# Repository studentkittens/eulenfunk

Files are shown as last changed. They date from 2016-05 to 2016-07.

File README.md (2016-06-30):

# Eulenfunk

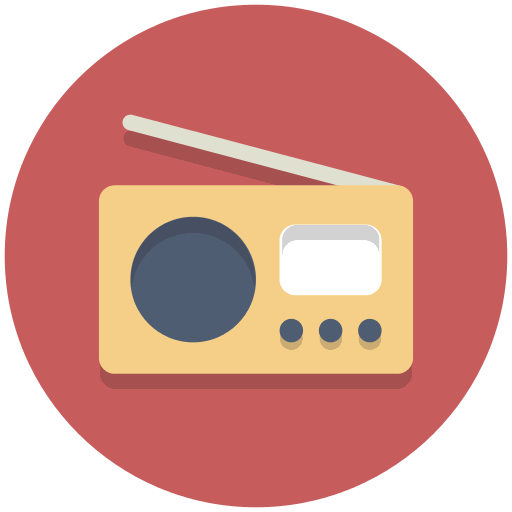
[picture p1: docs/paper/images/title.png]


A Webradio for the kitchen based on the Raspberry PI. [Go watch it in action!](https://vimeo.com/171646691)

The documentation can be found [here](https://studentkittens.github.io/eulenfunk/eulenfunk-doc.pdf).
Some slides [are available too](https://studentkittens.github.io/eulenfunk/index.html).

Sadly, both are in german. We're happy to answer questions though.

<iframe src="https://player.vimeo.com/video/171646691" width="640" height="360"
frameborder="0" webkitallowfullscreen mozallowfullscreen
allowfullscreen></iframe>

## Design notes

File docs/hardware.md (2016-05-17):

# Hardware-Komponenten

 - vorhanden:
    * RaspberryPi
    * LCD
    * Lautsprecher
    * Soundkarte
    * Ein-/Ausschalter
  
 - zu beschaffen:
    * Netzteil
    * Verstärker für Lautsprecher
    * Drehimpulsregler: ALPS-STEC11B03, evtl. 2x
    * muli-color-LED: Wieviele sind möglich?

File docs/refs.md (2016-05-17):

# Pin-Belegung/Rev:

http://www.raspberrypi-spy.co.uk/2012/09/checking-your-raspberry-pi-board-version/
http://www.hobbytronics.co.uk/raspberry-pi-gpio-pinout

# Archlinux ARM

https://archlinuxarm.org/platforms/armv6/raspberry-pi

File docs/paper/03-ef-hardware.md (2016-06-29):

# Hardware

## Anforderungen

Das Radio soll dem Benutzer folgende Hardwarekonfigurationsmöglichkeiten bieten:

* Anschluss passive Lautsprecher/Kopfhörer möglich 
* Lautstärkeregelung über Hardware möglich
* Verwendung des internen Lautsprechers des alten Radios
* Statusinformationen zum aktuellen Lied beispielsweise über ein LCD
* LEDs als Statusanzeige und/oder als Visualisierungsvariante von Musik (vgl.
  [@wood2005techniques])
* USB--Anschlussmöglichkeit für externe Datenträger

## Komponenten und Bauteile

Abbildung \ref{uebersicht} zeigt eine konzeptuelle Übersichts des Zusammenspiels
der einzelnen Komponenten.

\begin{figure}[h!]
  \centering
  \includegraphics[width=0.8\textwidth]{images/uebersicht.png}
  \caption{Grobe Übersicht der verwendeten Komponenten im Zusammenspiel}
  \label{uebersicht}
\end{figure}

Folgende Hardwarekomponenten oder Bauteile waren bereits vorhanden oder mussten
noch erworben werden:

**Vorhanden:**

* Altes Gehäuse AEG 4104 Küchenradio[^AEG] 
* *Raspberry Pi* aus dem Jahr 2012 
* LCD--Anzeige (Altbestände u. Arduino--Kit)
* Kleinbauteile wie LEDs, Widerstände
* USB--Hub für Anschluss von beispielsweise ext. Festplatte 
* USB--Soundkarte 
* Wi--Fi--Adapter
* Netzteil (diverse 5V, 2A)

**Mussten noch erworben werden:**

* Audioverstärker (\EUR{6})
* Drehimpulsregler (\EUR{3})
* Kunststoffabdeckung für Front (\EUR{0})
* Farbe (Lack) (\EUR{5})
* Drehknöpfe für das Gehäuse (\EUR{2})
* Schrumpfschläuche (\EUR{1})
* Kippschalter (\EUR{6})

Insgesamt wurden für das Projekt ca. \EUR{23} ausgegeben.

[^AEG]: AEG Küchenradio 4104: \url{https://www.amazon.de/AEG-MR-4104-Desgin-Uhrenradio-buche/dp/B000HD19W8}

## Raspberry Pi

Der vorhandene *Raspberry Pi* ist aus dem Jahr 2012. Die genaue CPU-- und
Board--Revision kann auf Linux unter ``proc`` ausgelesen werden. Von der
Hardware--Revision kann auf die *Raspberry Pi*--Revision geschlossen werden,
siehe hierzu auch [@gay2014raspberry], Seite 46:

```bash
    $ cat /proc/cpuinfo 
    processor       : 0
    model name      : ARMv6-compatible processor rev 7 (v6l)
    BogoMIPS        : 697.95
    Features        : half thumb fastmult vfp edsp java tls 
    CPU implementer : 0x41
    CPU architecture: 7
    CPU variant     : 0x0
    CPU part        : 0xb76
    CPU revision    : 7

    Hardware        : BCM2708
    Revision        : 0003
    Serial          : 00000000b8b9a4c2
```

Laut Tabelle unter [@gay2014raspberry], Seite 45 handelt es sich hierbei um das
Modell B Revision 1+ mit 256MB RAM.

Je nach Raspberry Revision sind die Pins teilweise unterschiedlich belegt. Seit
Modell B, Revision 2.0 ist noch zusätzlich der P5 Header dazu gekommen.
Abbildung \ref{gpio}[^SRC] zeigt die GPIO--Header des *Raspberry Pi* Modell B Revision
1+.

### GPIO--Schnittstelle

\begin{figure}[h!]
  \centering
  \includegraphics[width=0.7\textwidth]{images/gpio.png}
  \caption{GPIO-Header des Raspberry Pi Modell B Rev 1.0+}
  \label{gpio}
\end{figure}

[^SRC]: Bildquelle:
\url{http://www.raspberrypi-spy.co.uk/2012/06/simple-guide-to-the-rpi-gpio-header-and-pins/\#prettyPhoto}

#### GPIO--Pinbelegung und Funktionalität

Die GPIO--Pins des *Raspberry Pi* haben eine Logikspannung von 3.3V und sind pro
GPIO--Pin mit max. 16mA belastbar. Der gesamte GPIO--Header sollte mit nicht
mehr als 50mA belastet werden, da es darüber hinaus zu Hardwareschäden kommen
kann (vgl. [@gay2014raspberry], Seite 121 ff.).

Die *Logik--Pegel* der GPIO--Pins sind beim
*Raspberry Pi* wie folgt definiert [vgl. @gay2014raspberry], Seite 129 ff.:

* $\le$ 0,8V, input low
* $\ge$ 1,3V, input high

Die Ansteuerung von LEDs über GPIO erfolgt binär. Das heißt, dass
die LED entweder aus (low) oder an (high) sein kann.

In der »analogen« Welt ist es jedoch möglich eine LED über das Senken der
Spannung zu dimmen. Um ein Dimmen in der digitalen Welt zu erreichen wird ein
Modulationsverfahren angewandt, welches Pulsweitenmodulation (*PWM*) heißt.
Unter [@richardson2014make], Seite 121 ff. und [@gay2014mastering], Seite 421
ff. finden sich weitere Informationen. Software PWM unter
[@gay2014experimenting], Seite 183 ff. zeigt beispielsweise eine 6% CPU--Last
pro GPIO--Pin bei einer PWM--Softwareimplementierung. Wie PWM in *Eulenfunk*
eingesetzt wird im Software--Kapitel unter dem Punkt \ref{internal-led-treiber}
beleuchtet.

## LCD--Anzeige

Um dem Benutzer --- beispielsweise Informationen über das aktuell gespielte Lied
--- anzeigen zu können, soll eine LCD--Anzeige verbaut werden. In den privaten
Altbeständen finden sich folgende drei Hitachi--hd44780--kompatible Modelle:

* Blaues Display, 4x20 Zeichen, Bolymin BC2004A
* Blaues Display, 2x16 Zeichen, Bolymin BC1602A
* Grünes Display, 4x20 Zeichen, Dispalytech 204B 

Für *Eulenfunk* wurde das blaue 4x20 Display --- aufgrund der größeren
Anzeigefläche und Farbe --- gewählt.

### Anschlussmöglichkeiten

Eine LCD--Anzeige kann an den *Raspberry Pi* auf verschiedene Art und Weise
angeschlossen werden. Anschlussmöglichkeiten für eine LCD--Anzeige wären
beispielsweise: 

* GPIO direkt (parallel)
* I2C--Bus (seriell)
* SPI--Bus (seriell)

Die serielle Anschlussmöglichkeit bietet den Vorteil, dass weniger Datenleitungen
(GPIO--Pins) verwendet werden. Für den parallelen Betrieb des Displays werden
mindestens sechs GPIO--Pins benötigt, für den seriellen Anschluss über I2C
lediglich nur zwei. 

Da für den seriellen Betrieb beispielsweise über den I2C--Bus zusätzliche
Hardware benötigt wird, wird die parallele Ansteuerung über die GPIO--Pins
bevorzugt. Weitere Informationen zum seriellen Betrieb über I2C sind unter 
[@horan2013practical], Seite 61, ff. zu finden.

\begin{figure}[h!]
  \centering
\includegraphics[width=0.7\textwidth]{images/lcdraspi.png}
  \caption{Verdrahtung von LCD im 4--Bit Modus und Raspberry Pi, alle hierzu benötigten
  Informationen sind im Datenblatt zu finden.}
  \label{lcd}
\end{figure}

Das Display arbeitet mit einer Logik--Spannung von 3.3V -- 5V. Da die GPIO--Pins
jedoch eine High--Logik von 3,3V aufweisen, würde man hier in der Regel einen
Pegelwandler bei bidirektionaler Kommunikation und 5V benötigen. Da aber auf das
Display nur zugegriffen und die GPIO--Pins nicht schreibend benutzt werden, kann
ein Betrieb des Displays auch mit 5V erfolgen. Beim 3.3V Betrieb welcher laut
Datenblatt[^LCD] auch möglich sein soll, hatte das Display leider nur eine sehr
schwachen beziehungsweise unzureichenden Darstellungskontrast, weswegen der 5V
Betrieb gewählt wurde. Zudem wurde an *Pin3* (LCD) ein 100$\Omega$ Potentiometer
hinzugefügt. Dies ermöglicht den Kontrast variabel einzustellen.

Die Hintergrundbeleuchtung des Displays wurde direkt über ein Potentiometer mit
2K$\Omega$ an die 5V Spannungsversorgung angeschlossen. Es wurde hier die
direkte Speisung vom Netzteil gewählt, um den GPIO--Header nicht unnötig zu belasten.

Laut Datenblatt kann die Hintergrundbeleuchtung entweder mit 3.4V ohne
Vorwiderstand oder mit 5V bei einem 27$\Omega$ Widerstand betrieben werden. Damit das
Display beim herunter geregeltem Potentiometer keinen Schaden nimmt, wurden
zusätzlich zwei Widerstände mit 100$\Omega$ (parallel geschaltet = 50$\Omega$) zwischen Display
und Potentiometer gehängt. Abbildung \ref{lcd} zeigt die Verdrahtung des LCD mit
dem *Raspberry Pi*.

Der resultierende Gesamtwiderstand ohne Potentiometer beträgt in diesem Fall
$\approx$ 50 $\Omega$:

$$  R_{ges} = \frac{R_1 \times R_2}{R_1 + R_2} = \frac{100\Omega \times 100\Omega}{100\Omega + 100\Omega} = 50\Omega $$

## Drehimpulsgeber

Um eine minimale Anzahl an Bedienelementen zu gewährleisten, wird bei *Eulenfunk*
ein Drehimpulsgeber mit Schalter gewählt. Für erste Testzwecke wurde von der
Hochschule ein *ALPS STEC12E08* bereitgestellt. Dieser wurde im Laufe der
Entwicklung durch einen *ALPS STEC11B09*[^ALPS] ersetzt, da dieser mittels Mutter und
Schraube am Gehäuse stabiler befestigt werden kann. 

Der verwendete Drehimpulsgeber hat insgesamt fünf Anschlüsse. Zwei
Signalleitungen (A und B), zwei mal *GND* (jeweils für Drehgeber und Schalter)
und einen Anschluss für den Schalter. Beim Drehen eines Drehimpulsgebers wird
ein Rechtecksignal generiert. Je nach Muster der beiden Datensignale A oder B,
kann entschieden werden ob es sich um eine Rechts-- oder Linksdrehung handelt.
Siehe [@2014projekte], Seite 361 ff. für weitere Hintergrundinformationen zum
Drehimpulsgeber.

Abbildung \ref{alps} zeigt den Anschluss des Drehimpulsgebers am *Raspberry Pi*. 

\begin{figure}[h!]
  \centering
\includegraphics[width=0.8\textwidth]{images/rotary.png}
  \caption{Drehimpulsgeber--Anschluss an den Raspberry Pi, Abbildung zeigt
  Kombination aus Potentiometer und Schalter.}
  \label{alps}
\end{figure}

\newpage

## Soundkarte

Die interne Soundkarte des *Raspberry Pi* ist über eine simple 
Pulsweitenmodulation realisiert. Die einfache Schaltung soll hier laut
Internetquellen[^AQ]eine sehr niedrige Audioqualität bieten.

Aus diesem Grund wird bei *Eulenfunk* auf das USB--Audio--Interface *BEHRINGER
U-PHONO UFO202*[^DAC] (USB--Soundkarte) gesetzt. 

[^LCD]: Datenblatt Bolymin BC2004A: \url{http://www.dema.net/pdf/bolymin/BC2004A-series_VER04.pdf}
[^ALPS]: Drehimpulsgeber ALPS STEC11B09: \url{https://www.reichelt.de/Drehimpulsgeber/STEC11B09/3/index.html?ACTION=3&GROUPID=3714&ARTICLE=73915}
[^DAC]:BEHRINGER U-PHONO UFO202 Audio Interface: \url{http://www.produktinfo.conrad.com/datenblaetter/1300000-1399999/001370864-an-01-de-BEHRINGER_UFO_202_AUDIOINTERFACE.pdf}
[^AQ]: Raspberry Pi onboard Sound: \url{http://www.crazy-audio.com/2013/11/quality-of-the-raspberry-pi-onboard-sound/}

## Audioverstärkermodul

Da eine Soundkarte in der Regel zu wenig Leistung hat, um einem Lautsprecher
»vernünftig« anzusteuern, wird ein Audioverstärker benötigt. Da neben dem
Anschluss von externen Lautsprechern auch eine Lautstärkeregelung über ein
Potentiometer erfolgen soll, ist die Entscheidung einfachheitshalber auf ein
Audioverstärker--Modul auf Basis vom PAM8403[^POW] Stereo-Verstärker mit
Potentiometer gefallen. Eine Do--It--Yourself--Alternative wäre ein
Transistor--basierter Audio--Verstärker, hier gibt es online diverse
Bauanleitungen[^amp2].

[^amp2]: Transistor--Verstärker:
\url{http://www.newsdownload.co.uk/pages/RPiTransistorAudioAmp.html}

Das Audioverstärker--Modul hat folgende Anschlusspins:

* Left--In, Right--In, GND
* 5V+ und GND (Betriebsspannung)
* Left--Side--Out (+), Left--Side--Out (-)
* Right--Side--Out (+), Right--Side--Out (-)

Laut diverser Onlinequellen[^MONO], dürfen die Ausgänge für einen Mono--Betrieb
eines auf dem PAM8403--basierten Verstärkers nicht parallel geschaltet werden.
Aus diesem Grund kommt ein 4--poliger
*EIN--EIN--Kippschalter*[^KIPPSCHALTER] zum Einsatz. So kann zwischen dem
internen Lautsprecher (Mono--Betrieb) und den externen Stereo
Lautsprecher--Anschlüssen sauber per Hardware hin und her geschaltet werden.

Damit im Mono--Betrieb nicht nur ein Kanal verwendet wird, ermöglicht
*Eulenfunk* das Umschalten zwischen Mono-- und Stereo--Betrieb in Software.

[^MONO]: PAM8403 Mono--Betrieb:
\url{http://electronics.stackexchange.com/questions/95743/can-you-bridge-or-parallel-the-outputs-of-the-pam8403-amplifier}

[^KIPPSCHALTER]: Kippschalter 4--polig EIN--EIN: \url{http://www.reichelt.de/Kippschalter/MS-500P/3/index.html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}
[^POW]: Verstärkermodul: \url{https://www.amazon.de/5V-Audioverstärker-Digitalendstufenmodul-Zweikanalige-Stereo-Verstärker-Potentiometer/dp/B01ELT81A6}

## LED--Transistorschaltung

Die Ansteuerung einer LED mittels GPIO--Pin ist recht simpel. Sollen jedoch
mehrere LEDs angesteuert werden, so wird in der Regel pro LED ein GPIO--Pin
benötigt. LEDs sollten nie ohne Vorwiderstand an den *Raspberry Pi*
angeschlossen werden, da durch den hohen Stromfluss die LED beschädigt werden
könnte. Weiterhin muss bei LEDs auch auf die Polung geachtet werden, die
abgeflachte Seite --- meist mit dem kürzerem Beinchen --- ist in der Regel die
Kathode (Minuspol). Abbildung \ref{led} zeigt exemplarisch den Anschluss einer
*classic LED rot*[^LEDS], mit einer Flussspannung von $U_{LED}$ $\approx$ 2V, die mit
einem Strom von $I_{LED}$ = 20 mA gespeist werden soll. Die Berechnung des
Vorwiderstandes erfolgt nach folgender Formel:

$$R_{LED} = \frac{U_{GPIO}-U_{LED}}{I_{LED}} = \frac{3.3V - 2V}{20mA}   \approx 65\Omega$$

[^LEDS]: Datenblatt mit verschiedenen LED--Typen: \url{https://www.led-tech.de/de/5mm-LEDs_DB-4.pdf}

**Hinweis:** Da ein GPIO--Pin aber mit nur max. 16mA belastet werden sollte,
sollte in unserem Beispiel durch 16mA anstatt 20mA geteilt werden um den max.
Stromfluss auf 16mA zu begrenzen. In diesem Fall würden wir auf $\approx$ 82$\Omega$ kommen.

Da Widerstände meistens in fest vorgegebenen Größen vorhanden sind, kann im Fall
eines nicht exakt existierenden Widerstandswertes einfach der nächsthöhere
Widerstandswert genommen werden. Im Beispiel wird ein $100\Omega$ Widerstand
verwendet. 

Weitere Beispiele und Grundlagen zur Reihen-- und Parallelschaltung von LEDs
können online beispielsweise unter *led-treiber.de*[^LED] eingesehen werden.

\begin{figure}[h!]
  \centering
\includegraphics[width=0.5\textwidth]{images/led.png}
  \caption{Anschluss einer roten LED mit Vorwiderstand am Raspberry Pi GPIO--Pin}
  \label{led}
\end{figure}

Je nach Typ und Farbe ist der benötigte Strom um ein vielfaches höher wie in
unserem Beispiel. Die in \ref{led} abgebildete LED kann vom GPIO--Pin nur einen
max. Strom von 16 mA beziehen

In *Eulenfunk* sollen mehrere intensiv leuchtende LEDs verbaut werden. Da die
GPIO--Pins in ihrer Leistung sehr begrenzt sind, würde es sich anbieten eine
externe Stromquelle zu verwenden. Um die Speisung über eine externe Stromquelle
zu ermöglichen, kann eine Transistorschaltung verwendet werden (vgl. [@exploring],
Seite 219 ff.). 

Für die Transistorschaltung wurden von Seite der Hochschule Augsburg NPN-- (BC547C) und
PNP--Transistoren (BC557C) bereitgestellt. Für den ersten Testaufbau wurde der
PNP--Transistor und eine RGB--LED[^RGBGM] mit gemeinsamen Minuspol verwendet.
Dabei ist aufgefallen, dass die LED ständig geleuchtet hat. Eine kurze Recherche
hat ergeben, dass der Transistor permanent durchgeschaltet war, weil die
Spannung an der Basis (GPIO--Pin, 3,3V) geringer war als die Betriebsspannung
für die LED (5V). 

Der zweite Testaufbau mit dem NPN--Transistor BC547C und einer RGB--LED[^RGBGP] mit
gemeinsamen Pluspol hat das gewünschte Ergebnis geliefert.

Da der Hersteller für die von der Hochschule bereitgestellten Transistoren
unbekannt ist, wurden typische Durchschnittswerte für die Dimensionierung der
restlichen Bauteile verwendet.

Wie es aussieht sind die meisten BC547C Transistor--Typen für einen max. Strom
$I_{CE}$=100 mA konstruiert. Für die Berechnung des Basis--Vorwiderstandes wird
der Stromverstärkungsfaktor $h_{FE}$[^HFE] benötigt. Je nach Hersteller
variieren die Werte zwischen 200[^FARI] und 400[^SEM]. Da der maximale Laststrom
$I_{CE}$ pro Transistor 60 mA (3 LEDs je max. 20mA) beträgt, sieht die
Berechnung des Basisstroms --- bei einem durchschnittlichem $h_{FE}$ = 300 --- wie folgt
aus:

[^LED]: Beispiele zur Ansteuerung von LEDs: \url{http://www.led-treiber.de/html/vorwiderstand.html}
[^HFE]:Stromverstärkungsfaktor: \url{http://www.learningaboutelectronics.com/Articles/What-is-hfe-of-a-transistor}
[^RGBGM]: RGB-LED Common Cathode: \url{http://download.impolux.de/datasheet/LEDs/LED 0870 RGB 5mm klar 10000mcd.pdf}
[^RGBGP]: RGB-LED Common Anode: \url{http://download.impolux.de/datasheet/LEDs/LED 09258 RGB 5mm klar 10000mcd_GP.pdf}

 $$I_{Basis} = \frac{I_{CE}}{h_{FE}} = \frac{0.06A}{300} \approx 200\mu A$$

Der BC547C Transistor benötigt eine durchschnittliche  $U_{BE}$ = 0,7V zum
Durchschalten. Die GPIO-Pins des *Raspberry Pi* haben einen Spannungspegel von
3.3V. Daraus ergibt sich folgende Berechnung des Basis--Vorwiderstandes:

$$R_{Basis} = \frac{U_{GPIO} - U_{Basis}}{I_{Basis}} = \frac{3,3V - 0,7V}{200\mu A} = 13k\Omega $$

[^SEM]: SEMTECH: \url{http://pdf1.alldatasheet.com/datasheet-pdf/view/42386/SEMTECH/BC547.html}
[^FARI]: Farichild Semiconductor: \url{https://www.fairchildsemi.com/datasheets/BC/BC547.pdf}

\begin{figure}[h!]
  \centering
\includegraphics[width=1\textwidth]{images/transistorled.png}
  \caption{Transistor--RGB--LED Schaltung}
  \label{transled}
\end{figure}

Damit der Transistor jedoch *sicher* durchschaltet, werden Wiederstände mit $10k
\Omega$ verwendet. Die in Abbildung \ref{transled} gelisteten
LED--Vorwiderstände ergeben sich aufgrund der verschiedenen Spannungen der
unterschiedlichen Farben[^RGBGP]. Die Berechnung für den Vorwiderstand pro LED
schaut am Beispiel der Farbe blau ($U_{LED} = 3,15V, I_{LED} = 20mA$) wie folgt
aus:

$$R_{LED} = \frac{U_{Betriebsspannung} - U_{LED}}{I_{LED}} = \frac{5V - 3,15V}{20mA} =92.5\Omega \approx 100\Omega$$

Analog errechnet sich für die Farbe rot ein Vorwiderstand von $145\Omega$ und für grün
ein Vorwiderstand von $87\Omega$.

## USB--Hub und Netzteil

Der *Raspberry Pi* hat in unserer Revision nur zwei USB--Schnittstellen, diese
sind bereits durch die Hardware--Komponenten USB--DAC (Soundkarte) und das
Wi--Fi--Modul belegt. Um den Anschluss eines externen Datenträgers, auch mit
größerer Last wie beispielsweise einer Festplatte zu ermöglichen, wird ein
aktiver USB--Hub benötigt.

Für diesen Einsatzzweck wird aus den Altbeständen ein *LogiLink 4 Port USB 2.0
HUB*[^HUB] verwendet. Viele billige Hubs arbeiten hier entgegen der USB--Spezifikation
und speisen den *Raspberry Pi* zusätzlich über die USB--Schnittstelle. Dieses
Verhalten wurde bemerkt, als der *Raspberry Pi* ohne Power--Connector alleine
nur mit der USB--Verbindung zum USB--Hub bootete.

[^HUB]: LogiLink USB--Hub: \url{https://www.amazon.de/LogiLink-4-Port-Hub-Netzteil-schwarz/dp/B003ECC6O4}

Bei der Speisung über die USB--Schnittstelle wird die interne Sicherungsschaltung
des *Pi* umgangen, deswegen wird in der Regel von einem Betrieb eines USB--Hub
mit *backfeed* abgeraten (vgl . [@suehle2014hacks], Seite 26 ff.). Für den Prototypen wird
jedoch der genannte USB--Hub und das dazugehörige Netzteil für den Betrieb von
*Eulenfunk* verwendet. Das Netzteil ist für 5V bei max. 2A ausgelegt.

**Nachtrag:** Die Speisung über das Netzteil des USB--Hubs ist recht instabil. Bei
Lastspitzen kommt es anscheinend zu Störeinwirkungen, die sich auf die
GPIO--Peripherie auswirken (LCD--Anzeige rendert inkorrekt). Ein weiterer Punkt
sind Störfrequenzen, welche teilweise in Form von Störgeräuschen die
Audioausgabe überlagern (Hintergrundgeräusche beim Einschalten aller LEDs).
Insgesamt wurden drei Netzteile --- jeweils 5V, 2A ---ausprobiert. Von diesen
war lediglich ein einziges als »akzeptabel« einzustufen. Die restlichen zwei
führen bei Lastspitzen zu Problemen (Abstürze, fehlerhaftes Rendering auf
Display, GPIO--Flips, et cetera). Das *backfeed* des USB--Hubs scheint die
genannten Probleme teilweise zu verstärken (vgl . [@suehle2014hacks], Seite 27).

## Gehäuse

### Vorderseite

Abbildung \ref{ral} zeigt ein Muster der Gehäusefront--Farbe hellelfenbeinweiß RAL
1015. Dieser Farbton wird für die Front verwendet, um *Eulenfunk* einen dezenten
»Retro«--Look zu verpassen.

\begin{figure}[h!]
  \centering
  \includegraphics[width=0.3\textwidth]{images/ral_soft.png}
  \caption{Muster RAL1015, hellelfenbeinweiß}
  \label{ral}
\end{figure}

Das Plexiglas für die Front wurde von der Firma *ira-Kunststoffe* in
Schwarzenbach/Saale zugeschnitten. In der Plexiglasfront wurden mit Hilfe von
Herrn Schäferling zwei 5mm Löcher (Drehimpulsgeber, Lautstärkeregler--Poti)
gebohrt. Anschließend wurde die Plexiglas--Front von der Innenseite
lackiert[^LACK], hierbei wurden die Flächen für LCD und die drei LEDs abgeklebt.
Zudem werden schwarze Knöpfe in Alu--Optik mit $\diameter$ 30mm  für den
Lautstärkeregler und den Drehimpulsgeber verwendet.

### Rückseite

Für die Rückseite wird die alte Abdeckung des AEG--Radios verwendet. Diese
musste teilweise leicht modifiziert werden. An dieser befinden sich zwei Potis
für Kontrastregelung und Hintergrundbeleuchtung des LCD, eine
USB--Female--Kabelpeitsche, zwei Cinch Stecker für externe Lautsprecher und ein
Kippschalter zum Umschalten zwischen internen und externen Lautsprechern.

[^LACK]: Buntlack, hellelfenbein: \url{http://www.obi.de/decom/product/OBI_Buntlack_Spray_Hellelfenbein_hochglaenzend_150_ml/3468725}

## Betriebssystem

Mittlerweile gibt es für den *Raspberry Pi* viele offiziell zugeschnittene
Betriebssysteme (vgl. [@pietraszak2014buch], Seite 29 ff. und [@warner2013hacking],
Seite 47 ff.). Bei den Linux--Distributionen ist *Raspbian* eine der bekanntesten Distribution -- welche auf
*Debian* basiert. *Raspbian* bringt ein komplettes Linux--basiertes System mit
grafischer Benutzeroberfläche mit sich. 

Neben den unter [@pietraszak2014buch], Seite 29 ff. genannten Distributionen
gibt es mittlerweile auch Windows 10 IoT (Internet of Things) für den *Raspberry
Pi*. Dieses speziell für den Embedded Bereich ausgerichtete Windows benötigt
jedoch eine ARMv7--CPU als Mindestanforderung[^WINIOT], was den »alten Raspberry«
ausschließt. Außerdem wäre für uns eine proprietäre Lösung ein
K.O.--Kriterium, da diese alle Vorteile von Freier Software zunichte machen
würde.

[^WINIOT]: Systemanforderungen:\url{http://raspberrypi.stackexchange.com/questions/39715/can-you-put-windows-10-iot-core-on-raspberry-pi-zero}

### Wahl des Betriebssystem

*Arch Linux ARM*[^ARCH] ist eine minimalistische und sehr performante
Linux--Distribution welche im Gegensatz zu *Raspbian* ohne Desktop--Umgebung
geliefert wird (vgl. [@schmidt2014raspberry], Seite 13 ff.) Darüber hinaus ist
*Arch Linux* ein bekannter Vertreter von Rolling--Release--Distributionen. Ein
weiterer Vorteil für unseren Einsatzzweck ist bei *Arch Linux* das *AUR*
(Arch User Repository)[^AUR], dieses erlaubt es eigene Software auf eine
schnelle und unkomplizierte Weise der Allgemeinheit zur Verfügung zu stellen.

### Einrichtung des Grundsystems

Nach der Installation[^INSTALL] und dem ersten Booten des Grundsystems muss die
Netzwerk--Schnittstelle konfiguriert werden. Arch Linux ARM bietet mit *netctl*
eine Profil--basierte Konfigurationsmöglichkeit. Ein Profil kann über das
*ncurses*--basierte Tool `wifi-menu` erstellt werden. In unserem Fall wurde das
Profil `wlan0-Phobos` erstellt. Anschließend kann das erstellte Profil mit
*netctl* verwendet werden. 

\newpage 

**Auflistung der bekannten Profile**

```bash
    [root@eulenfunk ~]$ netctl list
      eth0-static
      wlan0-Phobos
```

**Aktivierung des gewünschten Profils**

```bash
    # Starten des gewünschten Profils
    [root@eulenfunk ~]$ netctl start wlan0-Phobos
    [root@eulenfunk ~]$ netctl list
      eth0-static
    * wlan0-Phobos

    # Profil über System-Reboot hinweg aktivieren 
    [root@eulenfunk ~]$ netctl enable wlan0-Phobos

```

Nun verbindet sich der *Raspberry Pi* nach dem Hochfahren jedes Mal automatisch
mit dem Profil `wlan0-Phobos`.

[^AUR]: Arch User Repository: \url{https://aur.archlinux.org/}
[^ARCH]: Arch Linux ARM: \url{https://archlinuxarm.org/}
[^INSTALL]: Arch Linux Installation für Raspberry Pi: https://archlinuxarm.org/platforms/armv6/raspberry-pi#installation

## Erweiterungen und alternative Ansätze

### Allgemein

Der aktuelle Prototyp hat lediglich nur ein Potentiometer um die Hintergrundbeleuchtung
des LCD zu regeln. Ein anderer Ansatz wäre der Einsatz eines Relais, welches es
ermöglichen würde die LCD--Hintergrundbeleuchtung Software--seitig ein-- und auszuschalten.
Die Software könnte dann automatisch nach längerer Inaktivtät die Beleuchtung dimmen.

\label{internal-audio-vis}

### Audio--Visualisierung

Beim Projekt *Eulenfunk* wird die Visualisierung von Musik aufgrund der
begrenzten Zeit und Hardwareressourcen des *Raspberry Pi *über eine
vorberechnete Moodbar--Datei realisiert. Dieser Ansatz funktioniert bei nicht
live gestreamter Musik gut. Bei live gestreamter Musik könnte für die
Visualisierung eine Fast--Fourier--Transformation in Echtzeit durchgeführt
werden. Da jedoch die Ressourcen des *Raspberry Pi* sehr begrenzt sind, sollte hier
auf die Verwendung einer GPU--beschleunigten--FFT zurückgegriffen werden
(vgl. [@Sabarinath2015], Seite 657 ff.).

Ein alternativer Ansatz wäre auch die Realisierung einer Musik--Visualisierung
mittels Hardwarekomponenten. Ein möglicher Ansatz aus Hardware--basierten
Hochpass-- und Tiefpassfiltern in Form einer Disco--Beleuchtung wird unter
[@2014projekte], Seite 261 ff. beschrieben.

### Echtzeituhr

Der *Raspberry Pi* besitzt keine Hardware--Uhr. Aufgrund der Tatsache, dass es
sich bei *Eulenfunk* um ein Internetradio handelt wurde auf eine Echtzeituhr
(real time clock, RTC) verzichtet, da sich die Uhr von *Eulenfunk* aufgrund der
permanenten Internetverbindung mittels NTP[^NTP] über das Internet
synchronisieren kann. Eine Erweiterung um eine Echtzeituhr wird in
[@horan2013practical], Seite 145 ff. und [@gay2014experimenting], Seite 77 ff. ausführlich beschrieben.
Mit einer RTC wäre die Implementierung einer Weckerfunktion möglich, welche
das Radio gezielt zu einer bestimmten Uhrzeit aufweckt und Musik abspielt.

### Fernbedienung

Eine weitere Erweiterung wäre die Integration einer Fernbedienung. Diese ließe
sich relativ einfach mittels eines Infrarot--Sensors und beispielsweise der
*lirc*--Bibliothek umsetzen. Siehe auch [@warner2013hacking], Seite 190 ff. für
weitere Informationen.

### Batteriebetrieb

Da die Strom-- beziehungsweise Spannungsversorgung beim *Raspberry Pi*
problematisch ist, wäre auch ein Batterie-- beziehungsweise Akkubetrieb möglich.
Eine einfache Schaltung für einen Batteriebetrieb würde sich beispielsweise mit
einem *LM7805*--Spannungsregler oder einem Abwärtswandler realisieren lassen
([vgl. @gay2014mastering], Seite 24 ff.). 

[^NTP]: Network Time Protocol:
\url{https://de.wikipedia.org/wiki/Network_Time_Protocol}

## Fazit 

Grundsätzlich kann der Hardware--Prototyp als erfolgreich umgesetzt betrachtet werden.
Die geplanten Anforderungen an die Hardware konnten soweit alle umgesetzt
werden. Jedoch sollte gesagt werden, dass das Netzteil und der USB--Hub --- wie
bereits im  jeweiligem Kapitel erläutert --- aktuell ein eher instabiles
Verhalten aufweisen. Hier ist noch eine Umstellung auf einen besseren USB--Hub
(und Netzteil mit 5V, 3A) ohne *backfeed* nötig.

[^PIHUB]: Spezieller USB--Hub für den Raspberry Pi: \url{https://www.raspberrypi.org/blog/pihub-a-robust-powered-hub-for-your-pi/}

Auf der Seite des Betriebssystems wäre die relativ junge Linux--Distribution
*Alpine Linux*[^APL] eine mögliche Verbesserung für den Einsatzzweck
Internetradio. Diese Distribution hat ihren Fokus auf Ressourceneffizienz und
Systemsicherheit. Ein weiterer Vorteil wäre der `diskless mode`, welcher das
komplette Betriebssystem in den Arbeitsspeicher lädt. In diesem Modus müssen
Änderungen mit einem *Alpine Local Backup (lbu)*--Tool explizit auf die
Festplatte geschrieben werden. Das hätte den Vorteil, dass man die Abnutzung des
Flash--Speichers, durch unnötige Schreib/Lese--Vorgänge, minimieren würde.
Momentan unterstützt diese Distribution allerdings noch nicht das von uns
favorisierte ``systemd``.

[^APL]: Alpine Linux für Raspberry Pi: \url{https://wiki.alpinelinux.org/wiki/Raspberry_Pi}
\label{internal-software-anforderungen}

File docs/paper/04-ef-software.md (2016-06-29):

# Software

Dieses Kapitel beleuchtet die einzelnen Software--Komponenten von *Eulenfunk*.
Selbst verfasste Komponenten sind dabei als solche gekennzeichnet.

## Anforderungen

Zu Beginn der Entwicklung wurden einige Anforderungen an die Software
festgelegt:

1. Leichte Bedienbarkeit, obwohl es nur einen Knopf gibt, der nur die
   Aktionen »links drehen«, »rechts drehen« und Drücken zulässt.
2. Die Software sollte vernünftig mit den Hardwareressourcen des *Raspberry Pi*
   umgehen. Dabei sollte die Hardware nicht die ganze Zeit auf volle Last laufen,
   um eine Überhitzung im beengten Gehäuse zu vermeiden.
3. Die Software sollte möglichst ausfallsicher sein. Fällt beispielsweise ein
   Feature durch einen Absturz der Software aus, so sollten andere Teile des Radios
   nach Möglichkeit nicht betroffen sein. Auch sollte der abgestürzte Teil sich
   neu starten können und entsprechende Log--Nachrichten
   hinterlassen. Dienste, die von dem abgestürzten Dienst abhängen, sollten
   sich bei Neustart dessen wieder neu verbinden.
4. Leichte Wartbarkeit und Fehlersuche durch Schreiben von Logs.
5. Einfache Erweiterbarkeit und Integrierbarkeit mit anderen Anwendungen durch
   lose Kopplung von Diensten.

Inwieweit und wodurch diese Anforderungen erfüllt worden sind, wird im Fazit erläutert.

## Abspielsoftware

Für den Betrieb des Internetradios soll der MPD (Music--Player--Daemon)
verwendet werden, da *Eulenfunk* auf einem eigens entwickeltem MPD--Client
basieren soll. Andere Projekte greifen oft auf Abspielsoftware wie den *MOC*
[vgl. @pietraszak2014buch], Seite 189 ff. oder *mplayer* [@exploring] Seite 638
ff. zu. 

Der MPD ist ein unter Unix gern genutzter Daemon zum Verwalten und Abspielen von
Musik und Radiostreams. Er unterstützt dabei eine große Anzahl von Formaten und
kann diese an mehrere Backends wie ALSA, Pulseaudio oder als HTTP--Stream
ausgeben (siehe auch Abbildung \ref{mpd-overview}). Für unseren Einsatzzweck ist
er dabei aus zwei Gründen besonders geeignet: Auch bei sehr großen Sammlungen
mit einer 5-stelligen Anzahl von Liedern läuft er problemlos und mit einem
vergleichsweise niedrigen Speicherverbrauch. Der zweite Grund ist die lose
Kopplung zwischen Abspielsoftware und User--Interface: MPD selbst ist nur ein
Daemon, der mittels eines zeilenbasierten Textprotokolls (dem
MPD--Protokoll[^MPD-PROTO]) steuerbar ist. Um die Bedienoberfläche kümmert sich
dann ein separater MPD--Client, welcher als »Fernbedienung« für den Daemon
fungiert.

[^MPD-PROTO]: Details unter \url{https://www.musicpd.org/doc/protocol}

\begin{figure}[h!]
  \centering
  \includegraphics[width=0.85\textwidth]{images/mpd-overview.png}
  \caption{Übersicht über die Architektur des MPD--Daemons (Quelle: \url{http://mpd.wikia.com/wiki/What_MPD_Is_and_Is_Not})}
  \label{mpd-overview}
\end{figure}

## Softwarearchitektur

Die »Nachbaubarkeit« vieler Bastelprojekte ist häufig durch die Software recht
eingeschränkt, da diese entweder nicht frei verfügbar ist oder zu wenig
generisch ist als dass man die Software leicht auf das Projekt anpassen könnte.
Meist handelt es sich dabei um ein einziges, großes C--Programm oder ein eher
unübersichtliches Python--Skript. Aus diesem Grunde soll die
Software für *Eulenfunk* derart modular aufgebaut sein, dass einzelne Module
problemlos auch auf andere Projekte übertragbar sind und später eine leichte 
Erweiterbarkeit gewährleistet ist. Damit auch andere die Software einsetzen
können wird sie unter die GPL in der Version 3 (vgl. [@GplQuickstart]) gestellt.

Zu diesem Zweck ist die Software in zwei Hauptschichten unterteilt.
Die untere Schicht bilden dabei die *Treiber*, welche die tatsächliche
Ansteuerung der Hardware erledigen. Dabei gibt es für jeden Teil der Hardware
einen eigenen Treiber, im Falle von *Eulenfunk* also ein separates Programm für
die LCD-Ansteuerung, das Setzen der LED--Farbe und dem Auslesen des Drehimpulsgebers.

Die Schicht darüber bilden insgesamt fünf einzelne Dienste, die über eine
Netzwerkschnittstelle angesprochen werden und jeweils eine Funktionalität des
Radios umsetzen. So gibt es beispielsweise einen Dienst, der die Ansteuerung des
LCD--Displays *komfortabel* macht, ein Dienst, der die LEDs passend zur Musik
einfärbt und ein Dienst, der automatisch eine Playlist aus der Musik auf
angesteckten externen Speichermedien erstellt. Die jeweiligen Dienste sprechen
mit den Treibern indem sie Daten auf ``stdin`` schreiben, bzw. Daten von
``stdout`` lesen. Um die Dienste auf neue Projekte zu portieren, ist also nur
eine Anpassung oder Erweiterung der jeweiligen Treiber notwendig.

Der Vorteil liegt dabei klar auf der Hand: Die lose Kopplung der einzelnen
Dienste erleichtert die Fehlersuche ungemein und macht eine leichte
Austauschbarkeit und Übertragbarkeit der Dienste in anderen Projekte möglich.
Stellt man beispielsweise fest, dass der Prozessor des Radios voll ausgelastet
ist, so kann man mit Tools wie ``htop`` einfach herausfinden welcher Dienst dafür
verantwortlich ist.

### Sprachwahl

Die momentane Software ist in den Programmiersprachen *C* und *Go* geschrieben.
Dazu kommt lediglich ein einzelnes Bash--Skript zum Auslesen von Systeminformationen.

Die Ressourcen auf dem *Raspberry Pi* sind natürlich sehr limitiert, weswegen
sehr speicherhungrige Sprachen wie Java oder Ähnliches von vornherein
ausschieden. Obwohl Python nach Meinung des Autors eine schöne und komfortable
Sprache ist und viele gute Bibliotheken für den *Pi* bietet, schied es ebenfalls
aus diesem Grund aus.

Ursprünglich war sogar geplant, alles in *Go* zu schreiben. Leider gibt es nur
wenige Pakete für die GPIO--Ansteuerung und auch keine Bibliothek für
softwareseitige Pulsweitenmodulation. Zwar hätte man diese notfalls auch selbst
mittels ``/sys/class/gpio/*`` implementieren können, doch bietet *Go* leider auch
keine native Möglichkeit mit Interrupts zu arbeiten. Wie später beschrieben ist
dies allerdings für den Treiber nötig, der den Drehimpulsgeber ausliest.

Für *Go* sprechen ansonsten folgende Gründe als Sprache für die höhere Logik:

- **Garbage Collector:** Erleichtert die Entwicklung lang laufender Dienste.
- **Hohe Grundperformanz:** Zwar erreicht diese nicht die Performanz von C, 
  liegt aber zumindest in der selben Größenordnung (vgl. [@pike2009go], S. 37).
- **Weitläufige Standardbibliothek:** Kaum externe Bibliotheken notwendig.
- **Schneller Kompiliervorgang:** Selbst große Anwendungen werden in wenigen 
  Sekunden in eine statische Binärdatei ohne Abhängigkeiten übersetzt.
- **Kross--Kompilierung:** Durch Setzen der ``GOARCH=arm`` Umgebungsvariable kann 
  problemlos auf einen x86-64--Entwicklungsrechner eine passende
  ARM--Binärdatei erzeugt werden.
- **Eingebauter Scheduler:** Parallele und nebenläufige Anwendungen wie
  Netzwerkserver sind sehr einfach zu entwickeln ohne für jede Aufgabe einen neuen
  Thread starten zu müssen.
- Ein Kriterium war natürlich auch, dass die Autoren gute Erfahrung mit der Sprache
  hatten und **neugierig** waren, ob sie auch für solche Bastelprojekte gut einsetzbar
  ist.

``C`` ist hingegen für die Entwicklung der Treiber vor allem aus diesen Gründen
eine gute Wahl:

- Programmierung mit **Interrupts** bequem und nativ möglich.
- Hohe **Performanz** und genaue Kontrolle über den Speicherverbrauch.
- Verfügbarkeit von **wiringPi**.

## Überblick der einzelnen Komponenten

Ein Überblick über die existierenden Dienste liefert Abbildung
\ref{eulenfunk-services}. Die einzelnen Komponenten werden im Folgenden detailliert erläutert.

\begin{figure}[h!]
  \centering
  \includegraphics[width=1.0\textwidth]{images/eulenfunk-services.png}
  \caption{Übersicht über die Softwarelandschaft von \emph{Eulenfunk}. Dienste mit
  einer Netzwerkschnittstelle sind durch den entsprechenden Port gekennzeichnet.}
  \label{eulenfunk-services}
\end{figure}

### Vorhandene Softwarebibliotheken

``wiringPi`` (\url{http://wiringpi.com}): Eine Portierung der Arduino--``Wiring``
Bibliothek von Gordon Henderson auf den *Raspberry Pi*. Sie dient wie ihr
Arduino--Pendant zur leichten Steuerung der verfügbaren Hardware, insbesondere
der GPIO--Pins über ``/dev/mem``. Daneben wird für den LCD--Treiber auch die
mitgelieferte LCD--Bibliothek genutzt. Für den LED--Treiber wird zudem die
softwarebasierte Pulsweitenmodulation genutzt, allerdings in einer leicht
veränderten Form.

``go-mpd`` (\url{https://github.com/fhs/gompd}): Eine einfache MPD--Bibliothek, die
die wichtigsten Kommandos des MPD--Protokolls unterstützt. 

``go-colorful`` (\url{github.com/lucasb-eyer/go-colorful}): Eine Bibliothek um
Farben in verschiedene Farbräume zu konvertieren. Der Dienst, der die LED
passend zur Musik setzt, nutzt diese Bibliothek um RGB--Farbwerte in den
HCL--Farbraum zu übersetzen. Dieser eignet sich besser um saubere Übergänge
zwischen zwei Farben zu berechnen und Farbanpassungen vorzunehmen. 

``cli`` (\url{github.com/urfave/cli}): Eine komfortable und reichhaltige
Bibliothek, um
Kommandozeilenargumente zu parsen. Unterstützt Subkommandos ähnlich wie
``git``, welche dann wiederum eigene Optionen oder weitere Subkommandos
besitzen können. Beide Features wurden extensiv eingesetzt, um alle in *Go*
geschriebenen Dienste in einer Binärdatei mit konsistentem
Kommandozeileninterface zu vereinen.

## Treiber--Software

In Summe gibt es momentan drei unterschiedliche Treiber. Sie finden sich im
``driver/`` Unterverzeichnis[^driver_github] der Software nebst einem passenden
Makefile. Nach dem Kompilieren entstehen drei Binärdateien, welche mit dem
Präfix ``radio-`` beginnen:

- ``radio-led:`` Setzt die Farbe des LED--Panels auf verschiedene Weise.
- ``radio-lcd:`` Liest Befehle von ``stdin`` und setzt das Display entsprechend.
- ``radio-rotary:`` Gibt Änderungen des Drehimpulsgebers auf ``stdout`` aus.

Die genaue Funktionsweise dieser drei Programme wird im Folgenden näher beleuchtet.

[^driver_github]: Siehe auf GitHub: \url{https://github.com/studentkittens/eulenfunk/tree/master/driver}

\label{internal-led-treiber}

### LED--Treiber (``driver/led-driver.c``)

Der LED--Treiber dient zum Setzen eines RGB--Farbwerts. Jeder Kanal hat den
Wertebereich 0 bis 255. Die Hilfe des Programms zeigt die verschiedenen
Aufrufmöglichkeiten:

```html
    $ radio-led
    Usage:
      radio-led on  ....... turn on LED (white)
      radio-led off ....... turn off LED
      radio-led cat ....... read rgb tuples from stdin
      radio-led rgb  r g b  Set LED color to r,g,b
      radio-led hex  #RRGGBB Set LED color from hexstring
      radio-led fade ...... Show a fade for debugging
```

Erklärung benötigt hierbei nur der ``cat``--Modus, bei dem der Treiber
zeilenweise RGB--Farbtripel auf ``stdin`` liest und setzt. Dieser Modus wird benutzt,
um kontinuierlich Farben zu setzen ohne ständig das Treiberprogramm neu zu starten.

\begin{figure}[h!]
  \centering
  \includegraphics[width=1.0\textwidth]{images/eulenfunk-pwm.png}
  \caption{Grafische Darstellung der Pulsweitenmodulation mit zwei Beispielfrequenzen.
    Jeder weiße Block entspricht einem modulierten Wert. Die Prozentzahl darin entspricht dem »Duty--Cycle«
    (dt. Tastgrad). Zusammen mit dem Wertebereich ergibt sich aus ihm der eigentliche Wert.
    (z.B. $255 \times 0.2 = 51$)
  } 
  \label{eulenfunk-pwm}
\end{figure}

Da ein GPIO--Pin prinzipiell nur ein oder ausgeschaltet werden kann, verwenden
wir Pulsweitenmodulation (vgl. dazu [@gay2014experimenting], S 183). Dabei
macht man sich die träge Natur des menschlichen Auges zu Nutze indem man die
LED sehr schnell hintereinander ein-- und ausschaltet. Ist die LED dabei pro
Ein-- und Ausschaltvorgang genauso lange hell wie dunkel, so leuchtet die LED mit etwa
der Hälfte ihrer maximalen Leuchtstärke. Durch Verlängerung/Verkürzung des
eingeschalteten Zustands können so viele verschiedene Helligkeitsstufen
abgebildet werden. Eine beispielhafte Illustration findet sich in Abbildung
\ref{eulenfunk-pwm}

Da bei niedrigen Helligkeitswerten der ausgeschaltete Zustand besonders lange
gehalten wird, kann es dazu kommen, dass ein Flackern entsteht, da
man die ausgeschalteten Phasen als solche wahrnehmen kann. Um dies zu
verhindern, muss eine ausreichend hohe Frequenz gewählt werden. 

Anders als ursprünglich angenommen, mussten wir feststellen, dass die GPIO--Pins
des *Raspberry Pi* (mit Ausnahme von Pin 18 (vgl. [@gay2014experimenting], S.
185)) kein hardwareseitiges PWM unterstützen. Aus diesem Grund mussten wir auf
softwareseitiges PWM zurückgreifen, um Farben mit mindestens 256 Abstufungen zu
erhalten. Nach etwas Ausprobieren befanden wir die ``softPwm``--Bibliothek von
``wiringPi`` für tauglich.

Diese hat allerdings das Problem, dass eine hartkodierte Pulsweite von 100µs
verwendet wird. Für die meisten Anwendungsfälle und den vom Autor empfohlenen
100 Abstufungen ist das auch in Ordnung. Hundert unterschiedliche Zustände
waren nach kurzem Ausprobieren bei einem weichen Farbübergang zu stark
abgestuft, obwohl mit 100Hz kein nennenswertes Flackern sichtbar war:

$$T_{Periode} = 100\mu s\times 100= 10000\mu s = 0.01s$$

$$f = \frac{1}{T_{Periode}} = 100Hz$$

Optimal wären hier 256 unterschiedliche Zustände, um die volle 8--Bit Farbtiefe auszunutzen.
Daher mussten wir die entsprechende C--Datei kopieren (GPL3--lizenziert) und manuell anpassen.
Dabei haben wir die Pulsweite auf 50µs herabgesetzt, was bei einer Spanne von 256 Werten
eine Frequenz von optisch akzeptablen 78Hz ergibt:

$$T_{Periode} = 50\mu s\times 256 = 12800\mu s = 0.0128s$$

$$f = \frac{1}{T_{Periode}} = 78.125Hz$$

Diese Frequenz scheint optisch ausreichend flackerfrei zu sein und scheint die
CPU nicht übermäßig stark zu belasten (rund +3% Last pro Farbkanal).

Es besteht eine Verbindung zu einem früheren Bastelprojekt namens
``catlight``[^catlight] --- einer mehrfarbigen, in einem Gehäuse montierten LED,
die über USB angesprochen werden kann. Genutzt wird diese zur Benachrichtigung
bei neuen E--Mails, Chat--Nachrichten und Ähnlichem. Zu diesem Zwecke wurde
auch bereits damals ein Treiberprogramm entwickelt, welches das selbe
Bedienkonzept wie ``radio-led`` hat. Dies war während der Entwicklung von
*Eulenfunk* nützlich, da es die Entwicklung der Dienste ``ambilight`` und
``lightd`` unabhängig von der Fertigstellung der Radio--Hardware machte.

[^catlight]: Projektseite unter: \url{https://github.com/studentkittens/catlight}

### LCD--Treiber (``driver/lcd-driver.c``)

Der LCD--Treiber setzt Bereiche des LCD--Displays auf einen gegebenen Text.
Beim Start leert er das Display und liest ähnlich wie »``radio-led cat``«
zeilenweise von ``stdin`` und entnimmt diesen Zeilen die Information welcher
Bereich des Displays gesetzt werden soll. Das vom Treiber erwartete
Zeilenformat ist dabei ``LINENO[,OFFSET] TEXT...``, wobei ``LINENO`` die
gewünschte Zeilennummer als Dezimalzahl ist und der optionale ``OFFSET`` der
Index an dem geschrieben werden soll. Dahinter folgt durch ein Leerzeichen
getrennt beliebiger Text. Ist kein ``OFFSET`` gegeben, so wird die ganze Zeile
überschrieben und nötigenfalls mit Leerzeichen aufgefüllt. Ist der Text länger
als die Zeile wird der Text abgeschnitten.

Der Treiber hält eine Matrix mit den aktuell gesetzten Zeichen und kann daher ein erneutes
Zeichnen einer Zelle im Display verhindern, indem er das neue Zeichen mit dem Alten vergleicht.
Unnötige Zeichenvorgänge waren als störende Schlieren auf dem Display wahrnehmbar.

Zudem bietet der Treiber mit dem ``print-charset`` Argument die Möglichkeit, die
auf dem Display verfügbaren Zeichen aufs selbige auszugeben. Dazu stellt er
jeweils 80 Zeichen dar und wartet einige Sekunden bevor die nächsten 80
ausgegeben werden. Hat er alle 256 Zeichen ausgegeben beendet er sich. Optional
kann man auch ein Start- und End--Offset mitgeben, an dem er das Zeichnen
anfangen soll.

Der Treiber unterstützt eine Reihe hardkodierter Spezialzeichen (siehe Abbildung
\ref{eulenfunk-symbols}), welche in der
Menüführung und der UI benutzt werden. Das LCD unterstützt dabei 8
verschiedene *Custom Chars*, welche mittels der Codepoints 0-7 und 8-15
(wiederholt) setzbar sind. Momentan sind diese auf folgende Glyphen gesetzt:

\begin{figure}[h!]
  \centering
  \includegraphics[width=1.0\textwidth]{images/symbols.png}
  \caption{Spezielle, selbst gezeichnete Glyphen im Bereich 0-7 und 8-15. Gezeichnet mittels \url{https://omerk.github.io/lcdchargen}}.
  \label{eulenfunk-symbols}
\end{figure}

Die eigentliche Ansteuerung der Pins übernimmt dabei wieder die
``wiringPi``--Bibliothek, beziehungsweise dessen
LCD--Unterbibliothek[^WIRILCD]. Diese ist kompatibel mit dem populären Hitachi
HD44780 und Nachbauten. Das Display wird im 4--Bit Modus angesprochen. Das
heißt, dass nur vier Datenpins benötigt werden (bei uns Pin 25, 24, 23, und 18). 

[^WIRILCD]: Siehe: \url{https://projects.drogon.net/raspberry-pi/wiringpi/lcd-library}

### Drehimpulsgeber Treiber (``driver/rot-driver.c``)

Dieser Treiber kümmert sich um das Einlesen von Werten und Ereignissen vom
Drehimpulsgeber. Nach dem Start schreibt er alle registrierten Ereignisse auf
``stdout``. Dabei nimmt jede Zeile ein neues Ereignis ein. Die jeweilige Zeile
beginnt mit einem einzelnen Buchstaben und einem Leerzeichen, gefolgt von einem
Wert. Der Buchstabe beschreibt die Art des Ereignisses:

- ``v:`` Änderung des **V**alues durch Drehen des Knopfes.
- ``p:`` Der Knopf wurde gedrückt (eine ``1`` folgt) oder losgelassen eine
  (``0`` folgt).
- ``t:`` Der Knopf wurde für eine bestimmte Zeit gedrückt. Die Zeit folgt
  dahinter in Sekundenbruchteilen.

Initial wird zudem die Zeile ``v 0`` herausgeschrieben.

Technisch registriert sich der Treiber auf Änderungen an den GPIO--Pins 12, 13
(Pin A und B vom Drehimpulsgeber) und 14 (Button--Pin) mittels der
``wiringPi``--Funtkion ``wiringPiISR()``. Diese sorgt dafür, dass bei jeder
Wertänderung ein Interrupt aufgerufen wird. 

In der Interrupt--Routine wird der aktuelle Wert der Pins 12 und 13 ausgelesen und mit
dem vorherigen Wert verglichen. Dadurch ist es möglich zu entscheiden, in welche
Richtung der Drehknopf bewegt wurde ohne dass ein Prellen auftritt. Mehr
Informationen zum sogenannten »Grey Code« findet sich unter [@2014projekte], S.
362 und folgenden Seiten.

Da pro Einrastung des Drehknopfs ca. vier Interrupts getriggert werden, wird
auf eine globale Gleitkommazahl der Wert $\frac{1}{4}$ addiert. Beim Herausgeben
des Wertes wird der Wert dann auf den nächsten Integer gerundet.
Auch für jeden Knopfdruck wird ein Interrupt ausgelöst. Da der Knopf prellt,
wird hier mit einem niedrigen Timeout gearbeitet, welcher die Störsignale
filtert.

Da in Interrupts nur reentrante Funktionen aufgerufen werden sollten, werden nur
globale Flags in den Interruptfunktionen gesetzt. In der ``main``--Funktion
läuft eine Schleife mit einem Timeout von 50 Millisekunden, welche diese Werte
abholt, formatiert und auf ``stdout`` schreibt. Der ursprüngliche Code für
diesen Treiber stammt dabei von einem Blogpost[^BLOG]. Der Code wurde etwas
aufgeräumt und um Knopfdrücke sowie Ausgabe auf ``stdout`` erweitert.

[^BLOG]: Ursprünglicher Treiber: \url{http://theatticlight.net/posts/Reading-a-Rotary-Encoder-from-a-Raspberry-Pi}

## Service Software

Die folgenden Dienste implementieren die eigentliche Logik von *Eulenfunk*. 
Alle Dienste finden sich in einer gemeinsamen Binärdatei namens ``eulenfunk``:

```
$ eulenfunk help
NAME:
   eulenfunk - Control the higher level eulenfunk services

USAGE:
   eulenfunk [global options] command [command options] [arguments...]

VERSION:
   0.0.1

AUTHOR(S):
   Waldsoft <sahib@online.de> 

COMMANDS:
     info       Send mpd infos to the display server on the `mpd` window
     ui         Handle window rendering and input control
     automount  Control the automount for usb sticks filled with music
     lightd     Utility server to lock the led and enable nice atomic effects
     display    Display manager and utilites
     ambilight  Control the ambilight feature

GLOBAL OPTIONS:
   --width value   Width of the LCD screen (default: 20) [$LCD_HEIGHT]
   --height value  Height of the LCD screen (default: 4) [$LCD_HEIGHT]
   --help, -h      show help
   --version, -v   print the version
```

Details zu den Optionen der jeweiligen Dienste können mittels ``eulenfunk help
<service>`` angezeigt werden.

### ``displayd`` -- Der Displayserver

#### Einleitung

Der Displayserver ``displayd`` kümmert sich um die Verwaltung der
Display--Inhalte. Er bietet eine höhere Abstraktionsschicht als der
vergleichsweise simple LCD--Treiber. Dabei bietet er die Abstraktion von
*Zeilen*, *Fenstern* und erleichtert dem Programmierer Enkodierungsaufgaben
indem es ein Subset von Unicode unterstützt. Eine Zeile ist dabei ein beliebig
langer UTF8--enkodiertert Text ohne Zeilenumbruch. Die Zeile kann dabei länger
als das Display sein. In diesem Fall wird die Zeile abgeschnitten oder scrollt
je nach Konfiguration mit einer bestimmten Geschwindigkeit durch. Ein Fenster
hingegen ist eine benannte Ansammlung von Zeilen. Auch ein Fenster kann mehr
Zeilen haben als das Display physikalisch bietet. Vom Nutzer kann der
Fensterinhalt dann vertikal verschoben werden. Es können mehrere Fenster
verwaltet werden, aktiv ist dabei aber nur ein Ausgewähltes.

Die Idee diese Funktionalität in einem eigenen Daemon auszulagern, ist vom
Grafikstack in unixoiden Betriebssystemen inspiriert. Dabei kümmert sich
ebenfalls ein Displayserver um die Verwaltung der Inhalte (meist ``X.org`` oder
``Wayland``) indem er auf bestimmte Treiber zurückgreift. Der Nutzer kann dann
mittels eines festgelegten Protokolls mit dem Displayserver sprechen und so
unabhängig von der verwendeten Rendering--Methode Inhalte darstellen. Da das
Protokoll zwischen Client und Displayserver meist trotzdem zu komplex ist,
haben sich für diese Aufgaben simple UI--Bibliotheken wie Xlib oder komplexere
GTK+ und Qt etabliert. Auch die Fenster--Metapher wurde dabei von den
Fenstermanagern übernommen.

#### Architektur

Das Protokoll von ``displayd`` ist ein relativ simpel gehaltenes,
zeilenbasiertes Textprotokoll. Für den Zugriff auf dasselbige wird daher
auch keine UI--Bibliothek benötigt, lediglich einige Netzwerk-- und
Formatierungs--Hilfsfunktionen wurden implementiert[^LINEWRITER].
Basierend auf diesen Primitiven wurden aber auf Clientseite
Funktionalitäten wie Menü--»Widgets« implementiert, welche die grafische Darstellung
mit der Nutzereingabe verquicken.

[^LINEWRITER]: Siehe \url{https://godoc.org/github.com/studentkittens/eulenfunk/display\#LineWriter}

Neben diesen Aufgaben löst ``displayd`` ein architektonisches Problem:
Wenn mehrere Anwendung versuchen auf das Display zu schreiben, käme ohne zentrale
Instanz ein eher unleserliches Resultat dabei heraus. Durch ``displayd`` können
Anwendungen auf ein separates Fenster schreiben, wovon jeweils nur eines aktiv
angezeigt wird. Abbildung \ref{eulenfunk-displayd} zeigt die Architektur in der Übersicht.

\begin{figure}[h!]
  \centering
  \includegraphics[width=1.0\textwidth]{images/eulenfunk-displayd.png}
  \caption{Architekturübersicht von \texttt{displayd} mit Beispielfenstern.}
  \label{eulenfunk-displayd}
\end{figure}

Nach dem Start kann man auf Port 7777 ``displayd`` mittels eines simplen,
zeilenbasierten Textprotokolls kontrollieren. Dabei werden die folgenden
Kommandos (mit Leerzeichen--getrennten Argumenten) unterstützt:

```
switch <win>               -- Wechsle zum Fenster namens <win>.
line <win> <pos> <text>... -- Setze die Zeile <pos> im Fenster <win> zu <text>
scroll <win> <pos> <delay> -- Lässt Zeile <pos> in Fenster <win> mit <delay> scrollen.
move <win> <off>           -- Verschiebe Fenster <win> um <off> Zeilen nach unten.
truncate <win> <max>       -- Schneide Fenster <win> nach <max> Zeilen ab.
render                     -- Gebe aktuelles Fenster auf Verbindung aus.
close                      -- Schließt die aktuelle Verbindung.
quit                       -- Beendet Daemon und schließt Verbindung.
```

Dabei kann in die `<Platzhalter>` folgendes eingesetzt werden:

```
    <win>:   Ein valider Fenstername 
             (andernfalls wird ein neues Fenster mit diesen Namen angelegt)
    <pos>:   Eine Zeilennummer, beginnend bei 0 für die erste Zeile.
    <off>:   Ein Offset; 0 steht für keine Änderung; Kann negativ sein.
    <max>:   Maximale Zeilenanzahl nach der das Fenster abgeschnitten wird.
    <delay>: Zeitlicher Abstand zwischen zwei Scroll--Vorgängen.
             Siehe auch: https://golang.org/pkg/time/#ParseDuration
             Beispiel: 100ms
```

Für die tatsächliche Anzeige nutzt ``displayd`` wie oben erwähnt das
Treiberprogramm ``radio-lcd``. Dabei wird in periodischen Abständen (momentan
150ms) das aktuelle Fenster auf den Treiber geschrieben. Zukünftige Versionen
sollen dabei intelligenter sein und nur die aktuell geänderten Zeilen
herausschreiben. Allerdings hat sich herausgestellt, dass man mit mehreren
scrollenden Zeilen bereits mit diesem ereignisbasierten Ansatz auf eine höhere
Aktualisierungsrate kommt als mit den statischen 150ms. Eine Art »VSync«,
welches die Aktualisierungsrate intelligent limitiert wäre hier in Zukunft
wünschenswert.

#### Entwicklung mit ``displayd``

Da der *Raspberry Pi* nur bedingt als Entwicklungsplattform tauglich ist
(langsamer Compile/Run Zyklus), unterstützt ``displayd`` auch
Debugging--Möglichkeiten. Im Folgenden werden einige Möglichkeiten gezeigt 
mit ``displayd`` zu interagieren, beziehungsweise Programme zu untersuchen,
die ``displayd`` benutzen:

```bash
    # Den display server starten; --no-encoding schaltet spezielles LCD encoding
    # ab welches auf normalen Terminals zu Artefakten führt. 
    $ eulenfunk display server --no-encoding &

    # Gebe in kurzen Abständen das "mpd" Fenster aus.
    # (In separaten Terminal eingeben!)
    $ eulenfunk display --dump --update --window mpd

    # Verbinde zu MPD und stelle aktuellen Status auf "mpd" Fenster dar.
    # (auch in separaten Terminal eingeben)
    $ eulenfunk info
    # Auch nach Unterbrechung wird der zuletzt gesetzte Text weiterhin angezeigt:
    $ <CTRL-C>
    # Änderungen sind auch möglich indem man direkt mit dem Daemon über telnet
    # oder netcat spricht. Hier wird die erste Zeile überschrieben, das aktuelle
    # Fenster angezeigt und dann die Verbindung geschlossen.
    $ telnet localhost 7777
    line mpd 0 Erste Zeile geändert!
    render                        
    (... Ausgabe ...)
    close
```

#### LCD--optimierte Enkodierung

Das LCD unterstützt 8--bit pro Zeichen. Dabei sind die ersten 127 Zeichen
weitestgehend deckungsgleich mit dem ASCII--Standard. Lediglich die Zeichen 0 bis
31 sind durch *Custom Chars* und einige zusätzliche Zeichen belegt. Dies ist
insofern auch sinnvoll, da in diesem Bereich bei ASCII Steuerzeichen definiert
sind, die auf dem LCD schlicht keinen Effekt hätten.

Die Zeichen 128 bis 255 sind vom Hersteller des Displays mit verschiedenen
Symbolen belegt worden, die keinem dem Autor bekannten Encoding entsprechen. Da
auch nach längerer Internetrecherche keine passende Encoding--Tabelle gefunden
werden konnte, wurde (in mühevoller Handarbeit) eine Tabelle erstellt, die
passende Unicode--Glyphen auf das jeweilige Zeichen des Displays abbildet.
Nicht erkannte UTF8--Zeichen werden als ein »?« gerendert anstatt Zeichen die
mehrere Bytes zur Enkodierung (wie » $\mu$  «) als mehrere falsche Glyphen
darzustellen. So wird beispielsweise aus dem scharfen »ß« das Zeichen 223.
Diese Konvertierung wird transparent von ``displayd`` vorgenommen, wodurch es
möglich wird die meisten Musiktitel und Ähnliches annäherend korrekt darzustellen.

Abbildung \ref{eulenfunk-encoding} zeigt das erstellte Mapping zwischen Unicode und LCD--Display.
Folgende Seiten waren bei der Erstellung der Tabelle hilfreich:

* \url{http://www.amp-what.com} (Suche mittels Keyword)
* \url{http://shapecatcher.com} (Suche mittels Skizze)

\begin{figure}[h!]
  \centering
  \includegraphics[width=1.0\textwidth]{images/encoding.png}
  \caption{Unicode--Version der LCD--Glyphen. Der normale ASCII--Bereich (32-127) wurde ausgelassen.}
  \label{eulenfunk-encoding}
\end{figure}

### ``lightd`` -- Der Effektserver

``lightd`` ist ein relativ einfacher Service, dessen Hauptaufgabe die
Verwaltung des Zugriffs auf die LEDs ist. Wollen mehrere Programme die LED
ansteuern, um beispielsweise einen sanften roten und grünen Fade--Effekt zu
realisieren, so würde ohne Synchronisation zwangsläufig eine zittrige Mischung
beider Effekte entstehen.

Ursprünglich war ``light`` als »``lockd``« konzipiert, der den Zugriff auf
verschiedene Ressourcen verwalten kann. Da aber das Display bereits von
``displayd`` synchronisiert wird und durchaus mehrere Programme den Drehknopf
auslesen dürfen, wurde diese etwas generellere Idee wieder verworfen.

Die zweite Hauptaufgabe von ``lightd`` ist die Darstellung von Farbeffekten auf
der LED. Ursprünglich waren diese dafür gedacht, um beispielsweise beim Verlust
der WLAN--Verbindung ein rotes Blinken anzuzeigen. Momentan wird allerdings nur
beim Herunterfahren bzw. Rebooten ein rotes bzw. oranges Blinken angezeigt.
Folgende Effekte sind also momentan als Möglichkeit zur Erweiterung zu
begreifen:

- ``blend:`` Überblendung zwischen zwei Farben.
- ``flash:`` Kurzes Aufblinken einer bestimmten Farbe.
- ``fade:`` Lineare Interpolation von schwarz zu einer bestimmten Farbe und zurück.
- ``fire:`` Kaminfeuerartiges Leuchten.

Wie andere Dienste wird auch ``lightd`` mittels einer Netzwerkschnittstelle kontrolliert.
Die möglichen Kommandos sind dabei wie folgt:

```
!lock      -- Versuche exklusive Zugriffsrechte zu erlangen oder warte bis möglich.
!unlock    -- Gebe exklusive Zugriffsrechte zurück.
!close     -- Schließe die Verbindung.
<effect>   -- Auszuführender Effekt, siehe unten.
```

``<effect>`` darf dabei folgendes sein:

```
    {<r>,<g>,<b>}                              -- Einzelne Farbe.
    blend{<src-color>|<dst-color>|<duration>}  -- Blend Effekt.
    flash{<duration>|<color>|<repeat>}         -- Flash Effekt.
    fire{<duration>|<color>|<repeat>}          -- Fire Effekt.
    fade{<duration>|<color>|<repeat>}          -- Fade Effekt.
```

Der Platzhalter ``<*-color>`` steht dabei für eine einzelne Farbe.
``<duration>`` ist eine zeitliche Dauer und ``<repeat>`` eine Ganzzahl, die beschreibt wie oft
der Effekt wiederholt wird.

Die Farbe wird, ähnlich wie bei ``displayd``, auf ``stdin`` von ``radio-led`` geschrieben.

### ``ambilightd`` -- Optische Musikuntermalung

Ein »Gimmick« von *Eulenfunk* ist es, dass die LED entsprechend zur momentan
spielenden Musik eingefärbt wird. Hier erklärt sich auch der Name dieses
Dienstes: *Ambilight* (vgl. [@seuntiens2007visual]) bezeichnet eigentlich eine
von Phillips entwickelte Technologie, um an einem Fernseher angebrachte LEDs
passend zum momentanen Bildinhalt einzufärben. Hierher kommt auch die
ursprüngliche Idee, dies auf Musik umzumünzen.

Um aus den momentan spielenden Audiosamples eine Farbe abzuleiten, gibt es
einige Möglichkeiten (vgl. Kapitel \ref{internal-audio-vis}). Eine
große Einschränkung bildet hierbei allerdings die sehr begrenzte Rechenleistung
des *Raspberry Pi*. Daher haben wir uns für eine Variante entschieden, bei der die
Farbwerte vorberechnet werden. Das hat den offensichtlichen Nachteil, dass man
für Radiostreams kein Ambientlicht anzeigen kann. Andererseits möchte man das
bei Nachrichtensendung und Diskussionsrunden vermutlich auch nicht.

Zur Vorberechnung nutzen wir dabei das ``moodbar`` Programm (vgl. das Paper von
Gavin Wood[@wood2005techniques]). Dieses analysiert mit Hilfe des
GStreamer--Frameworks (vgl. [@taymans2013gstreamer]) eine Audiodatei in einem
gebräuchlichen Format und zerlegt diese in 1000 Einzelteile. Sehr oberflächlich
erklärt[^NOTE] wird für jedes dieser Teile ein Farbwert berechnet, wobei
niedrige Frequenzen tendenziell zu roten Farbtönen werden, mittlere Frequenzen
zu Grüntönen und hohe Frequenzen zu blauen Tönen werden. Die so gesammelten
Farbwerte werden dann in einer ``.mood``--Datei gespeichert, welche aus 1000
RGB--Tripeln à 3 Byte (1 Byte pro Farbkanal) bestehen. Ein visualisiertes
Beispiel für eine Moodbar kann man in Abbildung \ref{queen-moodbar} sehen.

[^NOTE]: Der eigentliche Algorithmus ist komplexer und wird im referenzierten Paper beschrieben.

\begin{figure}[h!]
  \centering
  \includegraphics[width=1.0\textwidth]{images/we-will-rock-you-mood.pdf}
  \caption{Moodbar--Visualisierung des Liedes »We will rock you« von »Queen«.
  Das Fußstapfen und Klatschen am Anfang ist gut erkennbar.
  Die Visualisierung wurde mit einem Python--Skript des Autor erstellt 
  (\url{https://github.com/sahib/libmunin/blob/master/munin/scripts/moodbar\_visualizer.py})}
  \label{queen-moodbar}
\end{figure}

Um nun aber tatsächlich ein zur Musik passendes Licht anzuzeigen, muss für jedes
Lied in der Musikdatenbank eine passende Moodbar in einer Datenbank
abgespeichert werden. Diese Datenbank ist im Fall von *Eulenfunk* ein simples
Verzeichnis in dem für jedes Lied die entsprechende Moodbar mit dem Pfad
relativ zum Musikverzeichnis[^NOTE2] als Dateinamen abgespeichert wird.

[^NOTE2]: Wobei »/« durch »|« im Dateinamen ersetzt werden.

Die Datenbank kann dabei mit folgendem Befehl angelegt und aktuell gehalten werden:

```bash
$ eulenfunk ambilight --update-mood-db --music-dir /music --mood-dir /var/mood 
```

Die eigentliche Aufgabe von ``ambilightd`` ist es nun den Status von MPD zu
holen, die passende ``.mood``--Datei zu laden und anhand der Liedlänge und der
bereits vergangenen Zeit den aktuell passenden Sample aus den 1000
vorhandenen anzuzeigen. Damit der Übergang zwischen den Samples flüssig ist
wird linear zwischen den einzelnen Farbwerten überblendet. Da die LED eher zu
einer weißen Farbe tendiert, wenn mehrere Kanäle an sind, werden mittlere
Sättigungwerte leicht verstärkt und mittlere Helligkeitswerte etwas abgeschwächt.

\begin{figure}[h!]
  \centering
  \includegraphics[width=1.0\textwidth]{images/eulenfunk-ambilight.png}
  \caption{Konzeptuelle Übersicht über \emph{ambilight} und verwandte Dienste.}
  \label{eulenfunk-ambilight}
\end{figure}

Auch ``ambilight`` ist über Netzwerk über ein zeilenbasiertes Textprotokoll auf
Port 4444 ansprechbar. Es werden die Kommandos ``off`` (Halte ``ambilight``
Ausgabe an), ``on`` (Führe ``ambilight`` Ausgabe fort) und ``state`` (Zeige
aktuellen Status) unterstützt. Eine Übersicht über alle beteiligten Komponenten
von ``ambilight`` findet sich in Abbildung \ref{eulenfunk-ambilight}.

Im Fazit kann man sagen, dass die verwendete Technik durchaus gut für die meisten Lieder funktioniert.
Besonders die Synchronisation ist dabei erstaunlich akkurat und solange nur ein einzelnes Instrument spielt,
wird dem auch eine passende Farbe zugeordnet. Ein Dudelsack erscheint beispielsweise meist grün, während 
ein Kontrabass in mehreren Liedern rot erschien.

Lediglich bei schnellen Tempowechseln (Beispiel: »Prison Song« von »System of a
Down«) sieht man, dass der Farbübergang bereits anfängt bevor man den
zugehörigen Ton hört. Dem könnte im Zukunft abgeholfen werden, indem keine
lineare Interpolation zwischen den Farben genutzt wird, sondern ein
Verfahren, das plötzliche Übergänge eher berücksichtigt.

### ``automount`` -- Playlists von USB Sticks erstellen

\begin{figure}[h!]
  \centering
  \includegraphics[width=1.0\textwidth]{images/eulenfunk-automount.png}
  \caption{Beispielhafte Situation bei Anschluß eines USB Sticks mit dem Label »usb-music«}
  \label{eulenfunk-automount}
\end{figure}

Der ``autmount``--Daemon  sorgt dafür, dass angesteckte USB--Sticks automatisch gemounted werden,
Musikdateien darauf indiziert werden und in einer Playlist mit dem »Label« des Sticks landen.

Unter Linux kümmert sich ``udev`` um die Verwaltung  des
``/dev``--Verzeichnis. Zur Steuerung und Konfiguration erlaubt ``udev`` das
Anlegen von Regeln. Wird ein neues Gerät angesteckt, so geht ``udev`` alle
bekannten und auf das Gerät passende Regeln durch und wendet die darin
definierten Aktionen an.
Bei *Eulenfunk* wird die Regel ``config/udev/11-music-usb-mount.rules`` in das
Verzeichnis ``/etc/udev/rules.d`` kopiert. Die ``11`` im Namen sorgt dafur,
dass die Regel alphabetisch vor den Standardregeln abgearbeitet wird (beginnend
mit ``50``).  Abbildung \ref{eulenfunk-automount} zeigt danach den Ablauf beim
Anstecken eines USB--Sticks mit dem Label »usb-music«. Es wird von der
Regel aus ein Befehl über Netzwerk an ``automount`` gesendet, welcher dann das
Mount und Unmount samt Erstellen der Playlist übernimmt.
Die genaue Erklärung der Einzelheiten wird hier aus Platzgründen ausgelassen.
Weitere Informationen zu ``udev``--Regeln sind online[^UDEV][^UDEV2] zu finden.

[^UDEV]: Writing udev rules: \url{http://www.reactivated.net/writing\_udev\_rules.html}
[^UDEV2]: Arch Linux udev:
\url{https://wiki.archlinux.de/title/Udev\#Unter\_.2Fmedia\_einbinden.3B\_Partitions\_Label\_verwenden\_falls\_vorhanden}

Eine berechtigte Frage ist warum ``automount`` das Mounten/Unmounten des Sticks
übernimmt, wenn diese Aktionen prinzipiell auch direkt von der ``udev``--Regel
getriggert werden können. Der Grund für diese Entscheidung liegt am
*Namespace*--Feature von ``systemd`` (weit verbreitetes Init--System[^SYSTEMD]):
  Dabei können einzelne Prozesse in einer Sandbox laufen, der nur
begrenzten Zugriff auf seine Umgebung hat. Ruft man ``/bin/mount`` direkt aus
der Regel heraus auf, so wird der Mount im *Namespace* von ``udev`` erstellt
und taucht daher nicht im normalen Dateisystem auf.  Sendet man hingegen einen
Befehl an ``automount``, so agiert dieser außerhalb einer Sandbox und kann den
Stick ganz normal als ``root``--Nutzer mounten.

[^SYSTEMD]: \url{https://de.wikipedia.org/wiki/Systemd}

Beim Entfernen des USB--Sticks wird die inverse Operation ausgeführt: Die Playlist wird 
gelöscht (da MPD die Lieder nicht mehr abspielen könnte) und der Mount wird wieder entfernt.

Ähnlich wie die vorherigen Dienste unterstützt ``automount`` einige wenige
Befehle, die es über einen Netzwerk--Socket auf Port 5555 erhält:

* ``mount <device> <label>:`` Mounte ``<device>`` (z.B. ``/dev/sda1``) zu ``<music_dir>/mounts/<label>``
   und erstelle eine Playlist names `<label>` aus den Liedern.
* ``unmount <device> <label>:`` Entferne Playlist und Mountpoint wieder.
* ``close:`` Trenne die Verbindung.
* ``quit:``  Trenne die Verbindung und beende den Daemon.

### ``ui`` -- Menübasierte Bedienoberfläche

Die ``ui`` ist der einzige Dienst ohne Netzwerkschnittstelle. Er kümmert sich
um das Anlegen und Befüllen aller Fenster und um die Steuerung fast aller
anderen Dienste mittels einer menübasierten Oberfläche. Die genaue
Beschaffenheit der Oberfläche wird im nächsten Kapitel (siehe Kapitel
\ref{internal-owl-chapter}) im Stile eines Benutzerhandbuches beleuchtet. Daher
wird hier nur ein kurzer Überblick über die Technik dahinter gegeben.

Im momentanen Zustand existieren folgende Fenster:

- ``mpd:`` Zeigt Infos über das momentan laufende Lied oder den aktuellen Radiostream.
- ``clock:`` Zeigt das aktuelle Datum und Uhrzeit.
- ``stats:`` Zeigt Statistiken über die MPD--Datenbank an.
- ``sysinfo:`` Zeigt die Ausgabe des Skripts ``config/scripts/radio-sysinfo.sh`` an.
- ``about:`` Zeigt die Credits an.
- ``menu-main`` Hauptmenü von dem aus alle Funktionen erreichbar sind.
- ``menu-playlists:`` Zeigt alle verfügbaren Playlists.
- ``menu-power:`` Einträge zum Herunterfahren und Rebooten.

Fenster, die mit »``menu-``« beginnen, können durch Benutzung des
Drehimpulsgebers erkundet werden.
Eine Drehung nach rechts verschiebt das Menü nach unten, eine Drehung nach links nach oben.

Wie oben bereits erwähnt wurde ein kleines Client--seitiges »Toolkit« implementiert, welches die
leichte Erstellung von Menüs und die Verknüpfung mit dem Drehimpulsgeber mittels Aktionen möglich macht.
Der prinzipielle Aufbau dieses Toolkits ist in Abbildung \ref{eulenfunk-ui} gezeigt.

\begin{figure}[h!]
  \centering
  \includegraphics[width=1.0\textwidth]{images/eulenfunk-ui.png}
  \caption{Aufbau der Menüstruktur aus Entwicklersicht. Der Entwickler interagiert mit ``MenuManager``;
  dieser kümmert sich um die Ereignisverarbeitung.}
  \label{eulenfunk-ui}
\end{figure}

Der Programmierer muss dabei dem ``MenuManager`` nach dessen Anlegen lediglich eine Liste von Einträgen
mitgeben, die dieser verwalten soll. Es gibt momentan drei verschiedene Arten von Einträgen:

- ``SeparatorEntry:`` Zeigt einen vordefinierten Text. Wird zum Abtrennen verschiedener Sektionen
  innerhalb eines Menüs benutzt, daher der Name.
- ``ClickEntry:`` Zeigt einen Text und ist mit einer Aktion verknüpft. Drückt der Nutzer den Drehknopf 
  während der Fokus auf dem Eintrag ist, so wird die Aktion ausgeführt.
- ``ToggleEntry:`` Wie ``ClickEntry``, hat aber mehrere Zustände, die in eckigen Klammern hinter dem Text
  angezeigt werden. Ein Knopfdruck führt zum Weiterschalten zum nächsten Zustand. Dabei ist jeder Zustand
  mit einer Aktion verknüpft, die beim Umschalten ausgeführt wird.

Diese Einträge kann der Entwickler dann mit beliebigen Aktionen verknüpfen.
Daneben gibt es auch noch drei andere Aktionstypen, die unabhängig vom aktuellen
Eintrag ausgeführt werden:

- ``TimedActions:`` Wird der Knopf für eine bestimmte Zeit gehalten, kann nach
  einer bestimmten Zeit einmalig eine Aktion ausgeführt werden. Die Zeit nach
  der das passiert wird beim Registrieren der Aktion angegeben.
- ``ReleaseActions:`` Wird ausgeführt wenn der Knopf gedrückt wurde, aber
  kein Menüeintrag ausgeführt wurde.
- ``RotateActions:`` Wird ausgeführt sobald der Knopf nach rechts oder links
  gedreht wurde.

Auf Basis dieses minimalen Toolkits wurde dann eine leicht erweiterbare
Menüführung entwickelt. Eine genauere API--Beschreibung kann unter
``godoc.org``[^UI-GODOC] eingesehen werden.

[^UI-GODOC]: \url{https://godoc.org/github.com/studentkittens/eulenfunk/ui}

#### ``info`` -- Anzeige des ``mpd``--Status

``info`` ist der Teil der UI, welcher den Inhalt des ``mpd`` Fensters pflegt
und darstellt. Im Hintergrund steht dabei ein voll funktionsfähiger MPD--Client,
welcher auch auf Zustandsänderungen von außen reagiert. Das heißt: Ändert man
das aktuelle Lied mittels eines anderen MPD--Clients (von einem Handy als
Fernbedienung etwa), so wird die Änderung umgehend an die UI propagiert.

``info`` kann aus Gründen der Fehlersuche auch separat von der UI gestartet werden:

```bash
    $ eulenfunk info
```

### ``ympd`` -- MPD im Webbrowser

``ympd``[^YMPD-HOME] ist ein relativ populärer, in C geschriebener MPD--Client, der als
Webserver fungiert und eine Bedienung von MPD im Browser via Websocket möglich
macht. Auf *Eulenfunk* läuft er auf Port 8080 und kann von außen zugegriffen
werden. Abbildung \ref{ympd-screen} zeigt die Weboberfläche.

[^YMPD-HOME]: Homepage von ``ympd``: \url{https://github.com/notandy/ympd}

\begin{figure}[h!]
  \centering
  \includegraphics[width=1.0\textwidth]{images/ympd.png}
  \caption{Screenshot der ympd--Oberfläche mit laufenden Lied aus der Testdatenbank.}
  \label{ympd-screen}
\end{figure}

Ursprünglich war der Einsatz eines, in einer früheren Studienarbeit
entwickelten, Webclients namens »Snøbær« (siehe Abbildung \ref{snobaer-screen})
angedacht. Dieser hat ein paar mehr Features wie das automatische Herunterladen
von Coverart und Liedtexten. Leider lies sich dieser nicht ohne größeren Aufwand
auf dem *Raspberry Pi* kompilieren, weswegen aus Zeitgründen einstweilen auf ``ympd`` umgeschwenkt wurde.

\begin{figure}[h!]
  \centering
  \includegraphics[width=0.4\textwidth]{images/snobaer-small.png}
  \caption{Screenshot von Snøbær's Weboberfläche.}
  \label{snobaer-screen}
\end{figure}

#### Zeroconf

Normalerweise ist die Weboberfläche von *Eulenfunk* unter der Adresse
``http://eulenfunk:8080`` erreichbar.
Falls das wegen mangelnder Namensauflösung aber nicht funktioniert, kann 
man *Zeroconf* (vgl. [@ietf2013zero]) dazu nutzen die IP von *Eulenfunk* herauszufinden:

```bash
    $ avahi-browse _mpd._tcp -r | grep 'hostname = \[eulenfunk' -A 2
       hostname = [eulenfunk.local]
       address = [192.168.23.30]
       port = [6600]
```

Das funktioniert, weil der MPD--Server seine Anwesenheit mittels 
Zeroconf--Protokolls mitteilt. Es muss allerdings der Avahi--Daemon sowohl auf
dem anfragenden Rechner als auch auf *Eulenfunk* aktiv sein.

## Einrichtung

In diesem Teilkapitel soll die Einrichtung aller relevanten Komponenten dokumentiert werden.
Dies soll hauptsächlich zur Referenz dienen, um das Radio nachbauen zu können.

### ``mpd`` und ``ympd``

Installation aus den offiziellen Quellen (``mpd``) und aus dem AUR (``ympd``):

```bash
    $ pacman -S mpd mpc
    $ yaourt -S ympd
    $ mkdir -p /var/mpd/playlists
    $ touch /var/mpd/mpd.{db,state,log}
    $ cp eulenfunk/config/mpd.conf /var/mpd
    $ mpd /var/mpd/mpd.conf
    $ mpc update -w
```

``mpd`` und ``ympd`` sind die einzigen Dienste, die von Außen (ohne
Authentifizierung) zugreifbar sind. Auch wenn *Eulenfunk* normal in einem
abgesicherten WLAN hängt, wurde für die beiden Dienste jeweils ein eigener
Nutzer mit eingeschränkten Rechten und ``/bin/false`` als Login--Shell angelegt.

Im täglichen Betrieb wird die Musik von einem anderen Rechner via ``sshfs``
eingehängt. Dazu wurde in ``/etc/fstab`` ein Eintrag hinzugefügt[^SSHFS_FSTAB], der in
Verbindung mit ``systemd`` bewirkt, dass beim Zugriff auf das Musikverzeichnis
der Mount automatisch eingehängt wird.

[^SSHFS_FSTAB]: Siehe dazu: \url{https://wiki.archlinux.org/index.php/SSHFS\#On\_demand}

### ``systemd`` -- Start und Status von Diensten

``systemd`` ist ein sehr mächtiges Init--System welches zum Starten und Überwachen aller Dienste
in *Eulenfunk* eingesetzt wird. Im Gegensatz zu anderen Init--Systemen werden keine Shell--Skripte
zum Starten genutzt, sondern sogenannte Unit--Files. Diese regeln welche Binaries gestartet werden,
von was diese abhängen und was bei einem Crash passieren soll. Diese Dateien kopiert man in ein 
von ``systemd`` überwachtes Verzeichnis (beispielsweise ``/usr/lib/systemd/system``). Dort kann man
nach einem »``systemctl daemon-reload``« den Dienst starten und für den nächsten Bootvorgang vormerken:

```bash
    $ systemctl start my-unit-file    # Jetzt den Dienst starten.
    $ systemctl enable my-unit-file   # Beim nächsten Boot starten.
```

In Abbildung \ref{eulenfunk-systemd} ist schematisch der Abhängigkeitsgraph der
einzelnen Dienste von *Eulenfunk* gezeigt. Jeder relevante Dienst hat dabei ein
eigenes ``.unit``--File[^UNIT-FILES].

\begin{figure}[h!]
  \centering
  \includegraphics[width=0.9\textwidth]{images/eulenfunk-systemd.png}
  \caption{Abhängigkeits--Graph beim Start der einzelnen Dienste}
  \label{eulenfunk-systemd}
\end{figure}

[^UNIT-FILES]: Siehe GitHub für eine Auflistung aller Unit--Files: \url{https://github.com/studentkittens/eulenfunk/tree/master/config/systemd}

Sollte ein Dienst abstürzen, weil beispielsweise die Software doch noch Fehler
hat, dann wird der Service von ``systemd`` automatisch neu gestartet, da die
Option ``Restart=on-failure`` in den ``.unit``--Files von *Eulenfunk* gesetzt
ist. Besonders zur Fehlersuche war ``systemd`` bereits sehr hilfreich, da es
möglich, ist die Ausgabe des Dienstes im Nachhinein zu betrachten:

```bash
    $ systemctl status radio-ui.service
    * radio-ui.service - MPD client that show the current state on the LCD
      Active: active (running) since Mon 2016-06-27 23:45:55 CEST; 2h 0min ago
    [...]
    Jun 28 01:19:24 eulenfunk eulenfunk[410]: 2016/06/28 01:19:24 Pressed for 1s
    [...]
    # Alternativ falls mehrere Dienste zeitgleich angezeigt werden sollen:
    $ journalctl -u radio-ambilight.service -u radio-ui.service --since today
    [...]
```

### ``eulenfunk`` Software

Die Software selbst kann ohne große Abhängigkeiten direkt von *GitHub* installiert werden:

```bash
    $ pacman -S wiringpi go git
    $ git clone https://github.com/studentkittens/eulenfunk && cd eulenfunk
    $ mkdir -p /root/go
    $ export GOPATH=/root/go
    $ export GOBIN=/root/go/bin
    $ go get .
    $ make install
```

Das mitgelieferte Makefile installiert alle ``.unit``--Files, Skripte, Treiber--Binärdateien und die
``eulenfunk``--Binärdatei selbst. Die Software sollte dabei auch auf normalen Desktop--Rechnern
kompilierbar sein, ist dort aber mangels passender Treiber nur bedingt ausführbar.

## Fazit

Die Anforderungen können durchaus als erfüllt betrachtet werden. Anforderung
**#3** *(Ausfallsicherheit)*  und **#4** *(Wartbarkeit)* wurden durch den
konsequenten Einsatz von ``systemd`` umgesetzt. Anforderung **#5** *(Lose
Kopplung)* wird durch die Aufteilung der Dienste in einzelne, durch das Netzwerk
getrennte, Prozesse erreicht. Die Erweiterbarkeit sollte dadurch gewährleistet 
sein, dass relativ klar strukturierter und modularer Code verfasst wurde.
Möchte man sich mit dem Code vertraut machen, so hilft die
API--Dokumentation[^EULENFUNK] weiter.  

[^EULENFUNK]: API--Doc Eulenfunk: \url{https://godoc.org/github.com/studentkittens/eulenfunk}

Anforderung **#2** *(Effizienz)* wurde durch die Wahl effizienter
Programmiersprachen und Vermeidung ressourcenhungriger oder ineffizienter
Programmierung vermieden. Die CPU--Last bewegt sich dabei meist zwischen 40--60%
bei ``mp3``--enkodierten Liedern. Bei ``.flac``--Dateien liegt die Last etwa
10--20 Prozentpunkte höher. Die Speicherauslastung ist auch nach mehreren Stunden
Benutzung bei konstanten 50MB.

Auch wurde versucht, die Anzahl von gestarteten Prozess klein zu halten und
nur das Nötigste zu starten:

```html
    $ pstree -A
    systemd-+-2*[agetty]
            |-avahi-daemon---avahi-daemon
            |-dbus-daemon
            |-dhcpcd
            |-eulenfunk display-+-radio-lcd
            |-eulenfunk lightd-+-radio-led---3*[{radio-led}]
            |-eulenfunk ambilight-+-2*[radio-led---3*[{radio-led}]]
            |-eulenfunk automount---6*[{eulenfunk}]
            |-eulenfunk ui-+-radio-rotary
            |           |-radio-sysinfo.sh
            |-haveged
            |-mpd
            |-sshd---sshd---sshd---bash---pstree
            |-systemd---(sd-pam)
            |-systemd-journal
            |-systemd-logind
            |-systemd-resolve
            |-systemd-timesyn---{sd-resolve) S 1 
            |-systemd-udevd
            |-wpa_supplicant
            `-ympd
```

Inwiefern Anforderung **#1** (*leichte Bedienbarkeit*) gewährleistet ist, wird
das nächste Kapitel zeigen. Die Software darunter versucht die Möglichkeiten
dafür zu schaffen.

### Quelltextumfang

Mit dem Tool ``cloc`` (\url{https://github.com/AlDanial/cloc}) wurde eine
Statistik erstellt, welche den Umfang der Software zeigt. Diese Statistik wurde
bereits von auto--generierten Code und Fremdcode bereinigt:

| **Language** | **Files** | **Blank**  |  **Comment** | **Code** |
|---|---|---|---|---|
| *Go* | 32 | 991 | 550 | 4090 |
| *C* | 3 | 99 | 15 | 493 |
| *make* | 3 | 13 | 1 | 31 |
| *Bourne Shell* | 1 | 2 | 1 | 12 |
| *SUM: | 39 | 1105 | 567 | 4626 |

### Probleme und Verbesserungsmöglichkeiten

Obwohl die Software für den *Eulenfunk*--Prototypen bisher durchaus gut und stabil
funktioniert, gibt es natürlich noch Verbesserungspotenzial:

- Steckt ein USB--Stick nach einem Reboot noch am Radio, so wird dieser nicht
  automatisch gemounted. Erst nach einem An- und Abstecken desselben ist 
  die zugehörige Playlist wieder abspielbar. Beim Start müssten daher manuell
  ``udev``--Ereignisse getriggert werden. Versuche dies zu erreichen schlugen
  aber leider aus bisher ungeklärten Gründen fehl.
- In seltenen Fällen verschwindet der Cursor in Menüs aus ebenfalls ungeklärten Gründen.
- Wie im Kapitel von ``displayd`` beschrieben, wäre auf lange Dauer ein
  Ereignis-basierter Ansatz im Display--Server wünschenswert, um den
  Stromverbrauch im Ruhezustand zu senken.
- *Eulenfunk* benötigt zum Hochfahren momentan etwa 34 Sekunden. Das ist für die
  meisten Anwendungsfälle vollkommen ausreichend, könnte aber eventuell noch
  weiter optimiert werden. Eine genaue Übersicht darüber, welche Dienste wie lang
  zum Start brauchen, liefert das Tool ``systemd-analyze plot``. 
  Der aktuelle Plot kann online auf GitHub eingesehen werden[^BOOT-PLOT].

[^BOOT-PLOT]: \url{https://github.com/studentkittens/eulenfunk/blob/master/docs/paper/images/boot-plot.svg}

### Wettervorhersage

Eine praktische Erweiterung von *Eulenfunk* wäre die Anzeige der
Wettervorhersage für den aktuellen und die nächsten Tage. Oft wäre eine
entsprechende Information nützlich, um beispielsweise die Durchführung einer
Radtour zu planen oder ob man trockenen Fußes einkaufen gehen kann. Die Daten
könnte dabei von Online--APIs wie OpenWeatherMap[^OWM] geholt werden. Der Zugang
ist dort kostenlos, aber auf 60 Anfragen pro Minute limitiert.

[^OWM]: Mehr Informationen unter: \url{http://www.openweathermap.org/}

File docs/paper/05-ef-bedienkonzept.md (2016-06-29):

# Bedienkonzept/Menüsteuerung

\label{internal-owl-chapter}

## Anforderungen

Die Eingabe--Peripherie soll möglichst einfach gehalten werden, um eine *schöne*
Produkt--Optik zu gewährleisten, dabei sollen folgende Anforderungen erfüllt
werden:

* Minimale sowie ansprechende Bedienelemente
* Funktionales, zweckgebundenes *Design*
* *Retro--Look* wünschenswert

Das *Design* soll im Grunde *minimalistisch*  gehalten werden, das heißt, es
sollen aufgrund der Übersichtlichkeit nur so wenige »Bedienelemente« wie nötig
angebracht werden.

## Bedienelemente

\begin{figure}[h!]
  \centering
  \includegraphics[width=0.9\textwidth]{images/front_usage.png}
  \caption{Frontansicht von \emph{Eulenfunk}}
  \label{front_usage}
\end{figure}

Bei der Bedienung von *Eulenfunk* bestand die Herausforderung vor allem darin,
trotz minimaler Anzahl an Bedienelementen eine gute 
Bedienbarkeit (Usability) zu erreichen.

Zur Verfügung stehen primär ein Lautstärkeregler und ein Drehimpulsgeber (Abb. \ref{front_usage}).
Auf der Rückseite des Radios ermöglichen zusätzlich zwei Potentiometer die Regelung
der Beleuchtung und des Kontrastes vom Display. Mit einem Kippschalter kann
die Audioausgabe zwischen internen und externen Lautsprechern geschaltet werden.

Wie allgemein üblich, erhöht ein »nach rechts Drehen« des Lautstärkereglers 
die Lautstärke und »ein nach links Drehen« verringert die Lautstärke.

Der Drehimpulsgeber (im Weiteren Master-Regler genannt) ist für die gesamte Navigation innerhalb des Menüs und das Ausführen von
Aktionen zuständig. Drehen bewirkt grundsätzlich  ein *Vor* oder *Zurück*.
Drücken bewirkt das kontextbezogene Ausführen einer Aktion. Näheres wird bei 
den jeweiligen Menüansichten beschrieben.

## Menüinhalt

\begin{figure}[h!]
  \centering
  \includegraphics[width=0.9\textwidth]{images/hauptmenue.png}
  \caption{Ansicht des Hauptmenüs}
  \label{hauptmenue}
\end{figure}

Das Hauptmenü enthält drei Kategorien: Modes, Options und System (siehe Abb. \ref{hauptmenue}).
Ein Drehen des Master-Regler navigiert zwischen den einzelnen Einträgen.
Ein Drücken des Master-Regler öffnet den gewählten Eintrag als neue Ansicht
(Modes, System) oder setzt direkt andere Werte (Options).

\newpage

### Now Playing

\begin{figure}[h!]
  \centering
  \includegraphics[width=1.2\textwidth]{images/currentsong.png}
  \caption{Ansicht des Menüpunkts \emph{Now Playing} für Musikstücke und Radiosender}
  \label{currentsong}
  \end{figure}

Der Menüpunkt *Now Playing* zeigt Informationen des aktuell gespielten Mediums
an. Es gibt eine geringfügig abweichende Ansicht für Musikstücke und für
Radiosender. Wie in Abbildung \ref{currentsong} zu sehen ist, wird bei einem
Musikstück der Interpret, der Titel und das Album angezeigt. Sollte die Breite
des Displays für die Länge dieser Werte nicht ausreichend sein, »scrollt« die
Anzeige der Zeichen von rechts nach links durch. Die letzte Displayzeile zeigt
an, ob Musik spielt, oder pausiert ist. Außerdem wird die Bitrate und die
Spieldauer angezeigt. Die Ansicht für Radiosender enthält den Interpreten und
den Titel in Zeile eins, gefolgt vom Radiosender in Zeile zwei.

In beiden Ansichten führt ein Drücken des Master-Reglers zum Pausieren bzw. Abspielen
der Musik. Einen Titel bzw. Radiosender vor oder zurück wechseln ist durch Drehen des Reglers möglich.

\newpage 

### Playlists

\begin{figure}[h!]
  \centering
  \includegraphics[width=1.2\textwidth]{images/playlists.png}
  \caption{Ansicht des Menüpunkts \emph{Playlists}}
  \label{playlists}
\end{figure}

Der Menüpunkt *Playlists* (siehe Abb. \ref{playlists}) zeigt eine Übersicht der
aktuell verfügbaren Medien. Mögliche Listen sind Radiosender und Musikstücke.
Wird ein USB-Gerät an das Radio angeschlossen, erscheint er hier als Playlist.

Ein Drücken des Master-Reglers führt zur Auswahl einer Playlist. Anschließend
wechselt die Anzeige auf den Modus *Current Song*, d.h. die Informationen zum
aktuell aus der Playlist abgespielten Mediums werden angezeigt. Ein Drehen des
Master-Reglers navigiert innerhalb des Playlist--Ansicht. In der Ansicht
*Playlists* gibt es zusätzlich die Funktion *(Exit)*, die zum Hauptmenü führt.

### Clock

\begin{figure}[h!]
  \centering
  \includegraphics[width=1.2\textwidth]{images/clock.png}
  \caption{Ansicht des Menüpunkts \emph{Clock}}
  \label{clock}
  \end{figure}

  Der Menüpunkt *Clock* (siehe Abb. \ref{clock}) zeigt die aktuelle Uhrzeit, sowie das Datum an. 
  Ein Drücken des Master-Reglers führt zurück zum Hauptmenü. 

### Statistics

\begin{figure}[h!]
  \centering
  \includegraphics[width=1.2\textwidth]{images/statistics.png}
  \caption{Ansicht des Menüpunkts \emph{Statistics}}
  \label{statistic}
  \end{figure}

Der Menüpunkt *Statistics* (siehe Abb. \ref{statistic}) zeigt an, wieviele
Interpreten, Alben und Songs aktuell in der Musikdatenbank insgesamt zu finden
sind. Zusätzlich wird die Gesamtspieldauer angezeigt.

Ein Drücken des Master-Reglers führt zurück zum Hauptmenü.

### Options

\begin{figure}[h!]
  \centering
  \includegraphics[width=1.2\textwidth]{images/options.png}
  \caption{Ansicht der Kategorie \emph{Options}}
  \label{options}
  \end{figure}

  *Options* ist eine Kategorie, die keine Unteransichten hat (siehe Abb. \ref{options}).
Optionen werden direkt durch ein Drücken des Master-Reglers geändert.

- **Party!:** LEDs können aktiviert oder deaktiviert werden (Aus/Ein).
- **Output:** Umschalten zwischen stereo- und mono-Ausgabe (stereo, mono).
- **Playback:** Wechsel zwischen Abspiel-, Pause-, und Stopmodus (Play, Pause, Stop).
- **Random:** Zufällige Wahl eines Musikstücks aus der aktuell gewählten Playlist (Aus/Ein).

### Powermenu

\begin{figure}[h!]
  \centering
  \includegraphics[width=1.2\textwidth]{images/powermenu.png}
  \caption{Ansicht des Menüpunkts \emph{Powermenu}}
  \label{powermenu}
\end{figure}

Der Menüpunkt *Powermenu* (siehe Abb. \ref{powermenu}) enthält die Funktionen
*Poweroff* für das Herunterfahren des Systems und *Reboot* für einen Neustart des
Systems. Mit *(Exit)* gelangt man zurück ins Hauptmenü.

### Systeminfo

\begin{figure}[h!]
  \centering
  \includegraphics[width=1.2\textwidth]{images/systeminfo.png}
  \caption{Ansicht des Menüpunkts \emph{Systeminfo}}
  \label{systeminfo}
  \end{figure}

  Der Menüpunkt *Systeminfo* (siehe Abb. \ref{systeminfo}) zeigt folgende Informationen zum System an:

* CPU-Auslastung in Prozent.
* Speicher-Auslastung in Prozent.
* IP-Adresse, Systemlaufzeit,
* WLAN-Empfangsstärke in Prozent.
* CPU-Temperatur in Celsius.

Ein Drücken des Master-Reglers führt zurück zum Hauptmenü.

### About

\begin{figure}[h!]
  \centering
  \includegraphics[width=1.2\textwidth]{images/about.png}
  \caption{Ansicht des Menüpunkts \emph{About}}
  \label{about}
\end{figure}

Der Menüpunkt *About* (siehe Abb. \ref{about}) zeigt Informationen zu den Entwicklern des
Internetradios an.

## Shortcuts

Ein Direktzugriff auf das *Powermenu* (siehe [6.2.7](#powermenu)) ist durch
Drücken des Master-Reglers von drei Sekunden möglich --- in allen Anzeigemodi.
Das führt zu mehr Komfortabilität in der Bedienung. Es kann direkt ins
*Powermenu * gewechselt werden, ohne die aktuelle Anzeige verlassen zu müssen,
um manuell zum *Powermenu* zu navigieren.

In der Ansicht *Now Playing* führt ein längeres Drücken (mindestens 600ms) des Master-Reglers 
ins Hauptmenü. Eine Abweichung zu der Funktionsweise in den anderen Ansichten
war notwendig, weil auch der Wechsel zwischen Pause/Play möglich sein sollte.
Für eine möglichst intuitive Bedienung bot es sich an, dies durch ein einfaches
Drücken des Master-Reglers zu realisieren. Für den Wechsel ins Hauptmenü 
wurde deshalb ein längerer Drück--Zeitraum gewählt.

## Fazit

Die Möglichkeiten für die Darstellung der Inhalte waren aufgrund des 4x20 Displays
verständlicherweise begrenzt. Auch die Bedienung des Menüs über einen einzigen
Drehimpulsgeber setzt klare Grenzen für die Steuerung.

Trotz dieser minimalistischen Umstände, ist es gelungen, eine weitgehend konsistente
Menüführung umzusetzen. Nach einer kurzen Eingewöhnungsphase sollte das Bedienkonzept
gut funktionieren.

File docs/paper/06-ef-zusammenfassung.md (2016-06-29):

# Zusammenfassung

Das selbstgesetzte Ziel --- mit möglichst geringem finanziellen Einsatz (ca.
\EUR{23}) ein Internetradio auf Basis eines *Raspberry Pi* zu entwickeln ---
kann durchaus als erfolgreich betrachtet werden. 

Verbesserungsmöglichkeiten zum Projekt wurden bereits in den jeweiligen Kapiteln
aufgezeigt. Obwohl es online einige Internetradio--Projekte gibt, so ist
*Eulenfunk* aufgrund der selbst gesetzten Anforderungen durchaus als Unikat zu
bezeichnen und unterscheidet sich so grundlegend von den besagten Projekten,
welche meistens einen jeweils ähnlichen Ansatz verfolgen.

Die Dokumentation wurde absichtlich in der Art einer *Bauanleitung* verfasst,
da es sich hierbei um ein Free Software (und Hardware) Projekt handelt. Wir
würden uns daher sehr freuen, wenn Andere *Eulenfunk* nachbauen und
nach dem Open--Source--Gedanken weitere Verbesserungen und Vorschläge zurückfließen
lassen.

Abschließend möchten wir sagen, dass wir durch das Projekt --- gerade auf
Hardwareebene --- einiges gelernt haben und trotz des sehr knappen Zeitrahmens
von ca. drei Wochen viel Spaß bei der Entwicklung des Internetradios hatten.

# Literaturverzeichnis

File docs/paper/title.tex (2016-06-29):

\begin{titlepage}
\pagecolor{titlepagecolor}
\begin{center}

\bf
% Upper part of the page. The '~' is needed because \\
% only works if a paragraph has started.
%\includegraphics[width=0.25\textwidth]{docs/pics/title.png}~\\[1cm]
\color{titlepagefontcolor}
\textsc{\huge Hochschule Augsburg}\\[1.5cm]
\textsc{\LARGE Studienfach Hardwaresysteme}\\[0.5cm]
\vspace{1em}
~\\[1cm]

% Title
\rule{\linewidth}{0.5mm}
{\Huge \bfseries \frqq\texttt{Eulenfunk}\flqq \\ \Large{Ein Free Software
        Internetradio auf
Basis des Raspberry Pi}\\[0.4cm]}
\rule{\linewidth}{0.5mm}

% Author and supervisor
\noindent
\begin{minipage}[t]{0.4\textwidth}
\begin{flushleft} \Large
\emph{Studenten:}\\
\textnormal{Susanne \textsc{Kießling}} \\
\textnormal{Christopher \textsc{Pahl}} \\
\textnormal{Christoph \textsc{Piechula}}
\end{flushleft}
\end{minipage}%
\begin{minipage}[t]{0.4\textwidth}
\begin{flushright} \Large
\emph{Dozenten:} \\
\textnormal{Prof.\ Dr. Hubert\  \textsc{Högl}} \\
\textnormal{M.Sc. Michael \textsc{Schäferling}} 

\end{flushright}
\end{minipage}

\vfill

% Bottom of the page
{\large \today}
\end{center}
\end{titlepage}
\nopagecolor

\newpage

\thispagestyle{empty}
\vspace*{0in}
\begin{center}
  {\Large\reflectbox{\huge$_\copyright$}}\ Copyleft Piechula, Pahl, Kießling, 2016. \\
  Some rights reserved. \\
  \vspace{1in}
  \begin{minipage}[c]{0.2\linewidth}
    \hfill {\Huge \ccLogo~\ccAttribution}
  \end{minipage}
  \hspace{0.1cm}
  \begin{minipage}[c]{0.7\linewidth}
    Diese Arbeit ist unter den Bedingungen der \\
    \textit{Creative Commons Attribution--3.0} lizensiert. \\
    \url{http://creativecommons.org/licenses/by/3.0/de/}
  \end{minipage}
\end{center}
\vspace{6cm}
\textbf{Danksagung:} Wir danken Herrn Schäferling von der Hochschule Augsburg für die bereitgestellte Hardware und Unterstützung.
Ebenfalls danken wir Herrn Frank Müller und Roland Leuschner von \url{www.rf-elektronik.de} für die kompetente Beratung und bereitgestellten Bauelemente.
Auch der Firma \texttt{ira-kunststoffe} gebührt Dank für die kostenlose Plexiglasplatte.
\clearpage 

\newpage

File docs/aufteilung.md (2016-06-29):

---
documentclass: scrartcl
classoption: toc=listof,index=totoc
include-headers:
    - \usepackage{url} 
    - \usepackage[ngerman]{babel}
    - \usepackage{csquotes}
    - \usepackage[babel, german=quotes]{csquotes}
fontsize: 11pt
sections: yes
toc: no
tocdepth: 1
lof: no
lot: no
date: \today
---

# Arbeitsaufteilung beim Kür--Projekt »Eulenfunk«

Die Arbeit am Projekt »Eulenfunk« hat uns viel Spaß bereitet. Uns fällt es
jedoch schwer eine eindeutige Abgrenzung der Aufgaben zu treffen, da alle drei
Teilnehmer mehr oder minder an allen Teilen des Projektes beteiligt waren und
sich gegenseitig unterstützt haben. Aufgrund dieser Tatsache würden wir eine
Gruppennote bevorzugen, wenn möglich.

Grob gesagt lagen die Schwerpunkte wie folgt:

# Christoph Piechula  (``MN #944082``)

- Entwurf und Bau der Hardware.
- Dokumentation und Präsentation der Hardware.

# Christopher Pahl (``MN #944081``)

- Konzeption und Implementierung der Software.
- Dokumentation und Präsentation der Software.
 
# Susanne Kießling (``MN #948898``)

- Usability und Interface Design.
- Test und Validierung von Hard- und Software.
- Dokumentation und Präsentation der Usability
  und Teile von Hard- und Software.

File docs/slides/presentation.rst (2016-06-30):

:title: Eulenfunk
:author: Susanne Kiessling, Christopher Pahl, Christoph Piechula
:description: The Hovercraft! tutorial.
:keywords: presentation, backend, impress.js, hovercraft, go-lang
:css: presentation.css

----

.. utility roles

.. role:: underline
    :class: underline

.. role:: blocky
   :class: blocky

:id: first 

Projekt: **Eulenfunk**



----

:blocky:`Diese Praesentation...`

**gibt eine Übersicht über:**

- Unsere Wohngemeinschaft in Augsburg.
- Unser Open-Source-Project namens Eulenfunk.
- Den Weg vom Schrott zum Radio.
- Überblick über Vorbereitungen, Entwicklung und Testphase
- Probleme während der Umsetzung.

**...und soll Lust auf mehr machen!**

----

.. note::

    * Leben in einer WG zusammen
    * Alte Musikanlage erklaeren
    * Herausforderung für nicht-technischen Informatiker
    * Anforderungen: Nutzung vorhandener Hardware
    * Preis/Leistung
    * Moodbar (faszniniert von LEDs)
    * Erweiterbar

:blocky:`Dieses Eulenfunk...`

**...ist entstanden weil:**

- Aktuelle Musik-Situation... war kompliziert.
- Wir etwas für den täglichen Gebrauch bauen wollten.
- Alte Hardware vorhanden war.

**...ist anders weil:**

- Es kein Nachbau ist.
- Eigene Anforderungen umgesetzt wurden.
- Diamanten nur unter Druck entstehen.

-----

:blocky:`Bilder sagen manchmal mehr als...`

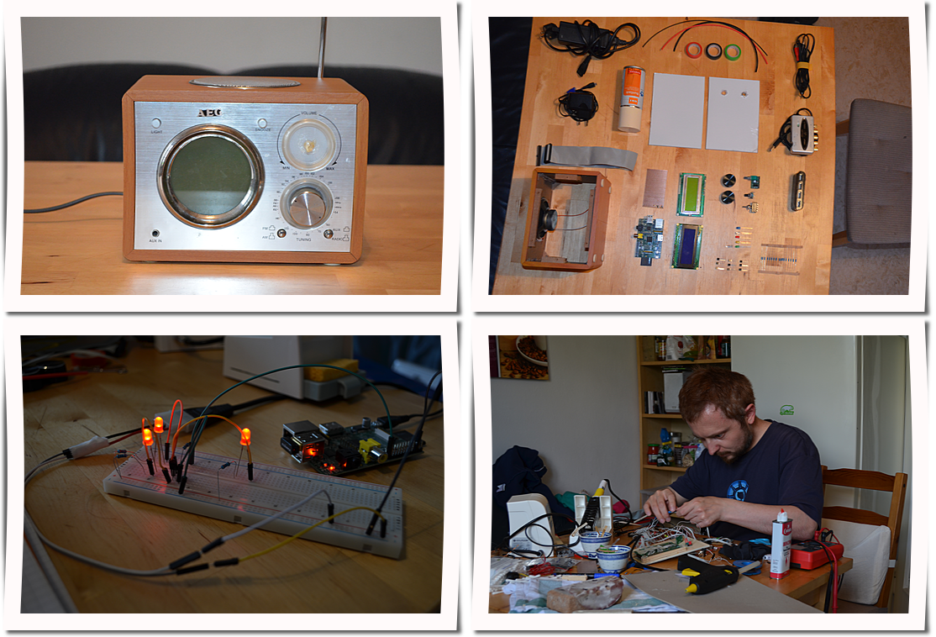
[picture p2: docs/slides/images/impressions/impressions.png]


-----

.. note:: 

    * Geschichte vom alten Radio (es war einmal)

:blocky:`Altes Analogradio:`

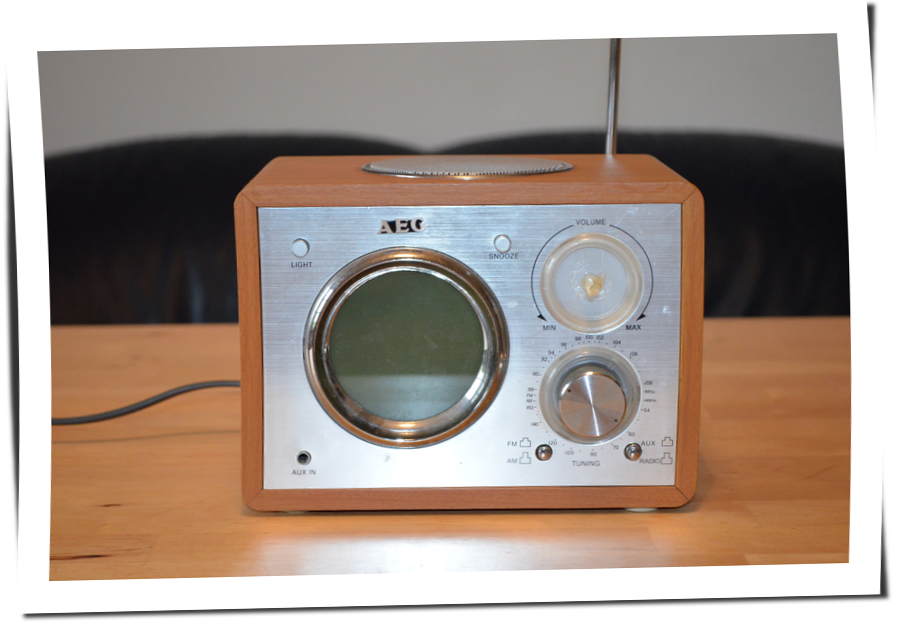
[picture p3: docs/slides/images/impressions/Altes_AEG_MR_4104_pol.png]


-----

.. note:: 

    * Komponenten kurz ansprechen
    * Preis/Leistungsverhaeltnis

:blocky:`Some assembly required:`

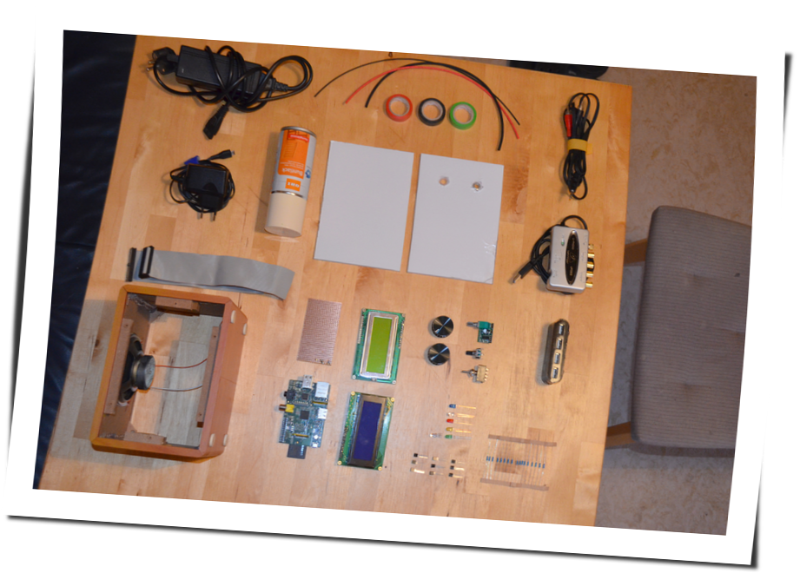
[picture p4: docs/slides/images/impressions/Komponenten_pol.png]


-----

.. note:: 

    * LCD Spannung und Anschluesse
    * Arduino Breadboard/Baukasten
    * Langsames Herantasten an Hardware

:blocky:`Testaufbau der Basiskomponenten`

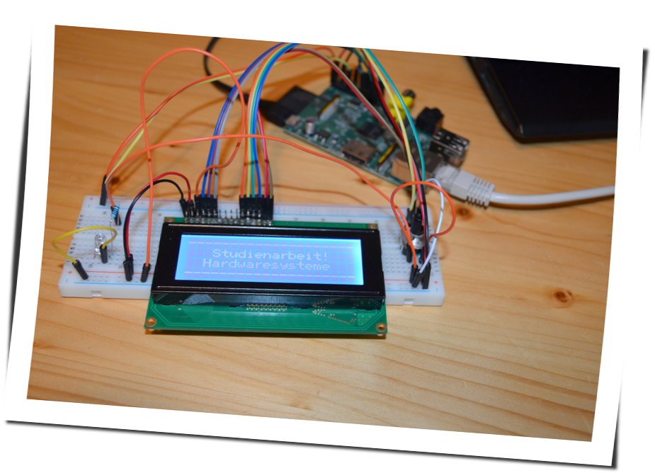
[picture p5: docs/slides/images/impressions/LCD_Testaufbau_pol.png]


-----

.. note::

    * Testaufbau Transistorschaltung.
    * Externes 5V Netzteil
    * PNP/NPN Problem

:blocky:`Testaufbau zur Ansteuerung der LEDs`

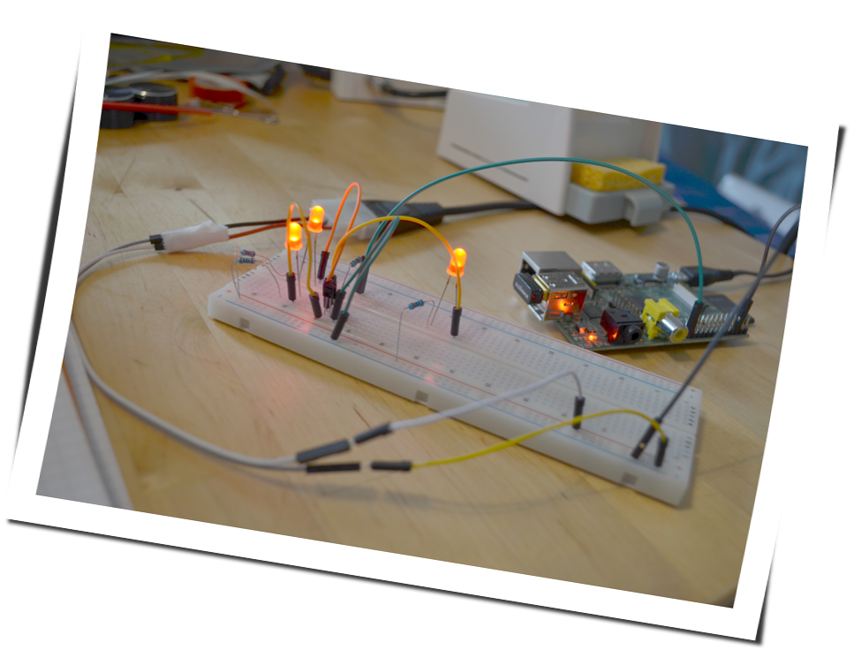
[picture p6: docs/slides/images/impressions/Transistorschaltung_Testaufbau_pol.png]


-----

.. note::

    * Von ira-kunststoffe und lackieren erzaehlen
    * Stundelange Diskussion welches Logo
    * Eigentlich ein Triforce...
    * ...aber jetzt ist es Neon Demon.

:blocky:`Lackierung`

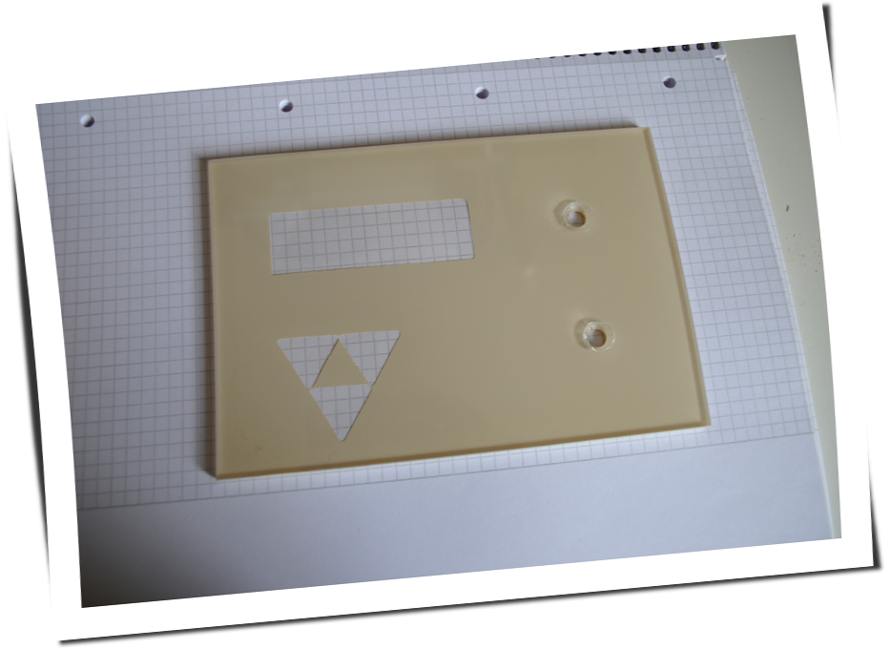
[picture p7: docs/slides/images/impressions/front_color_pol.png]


-----

.. note::

    * Drehimpulsgeber
    * Befestigung von Holzstuecken von Hand mit Messer zugeschnitten
    * Viel Heiskleber
    * Audioverstaerker
    * Chirugische Praezision
    * Triforce-Dimming Blende mit kuechenmesser zugeschnitten

:blocky:`Vorderseite von hinten`

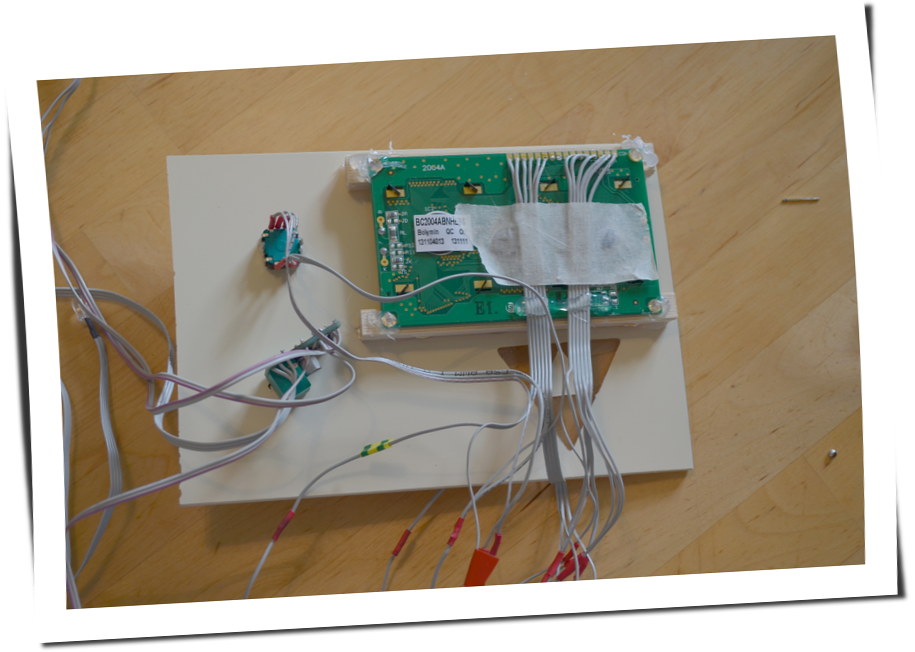
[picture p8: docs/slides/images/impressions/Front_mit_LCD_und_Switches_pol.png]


-----

:blocky:`Chirugische Praezision...`

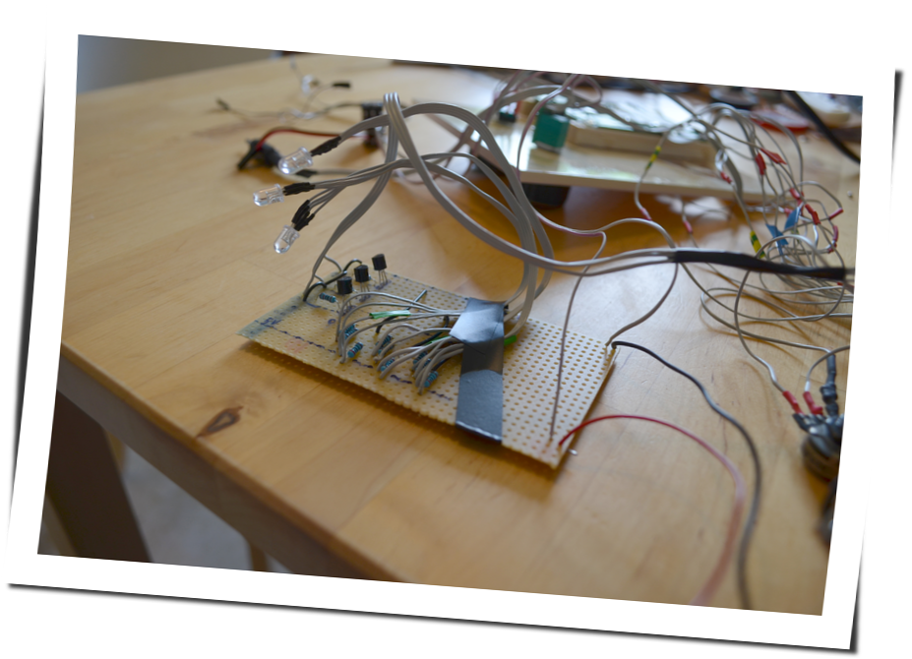
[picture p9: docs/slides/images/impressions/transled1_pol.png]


-----

.. note::

    * Eine Woche kuechenchaos...
    * Viel loetarbeiten und trial & error
    * Parallel beginn der Softwareentwicklung

:blocky:`Informatiker bei der Arbeit...`

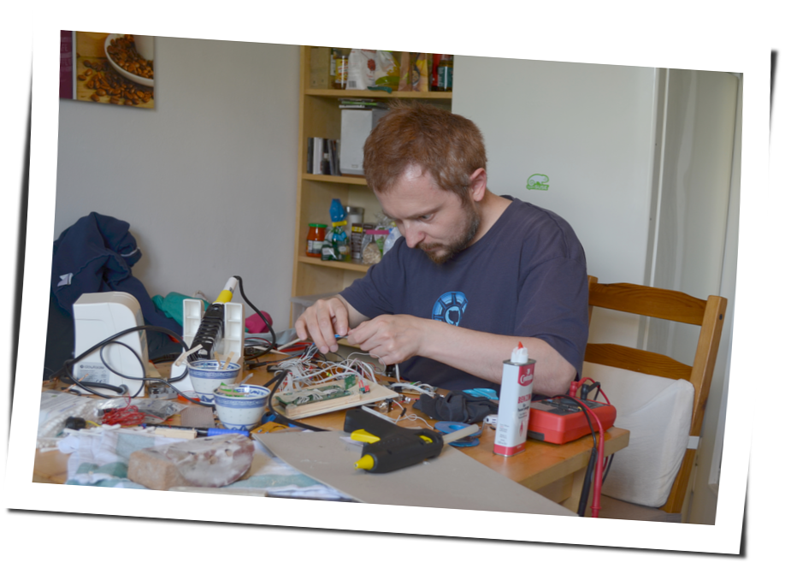
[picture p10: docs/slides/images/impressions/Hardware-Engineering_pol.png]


-----

:blocky:`Finaler Prototyp #1`

.. note::

    * Hoffentlich koennt ihr das lied nicht erkennen :)

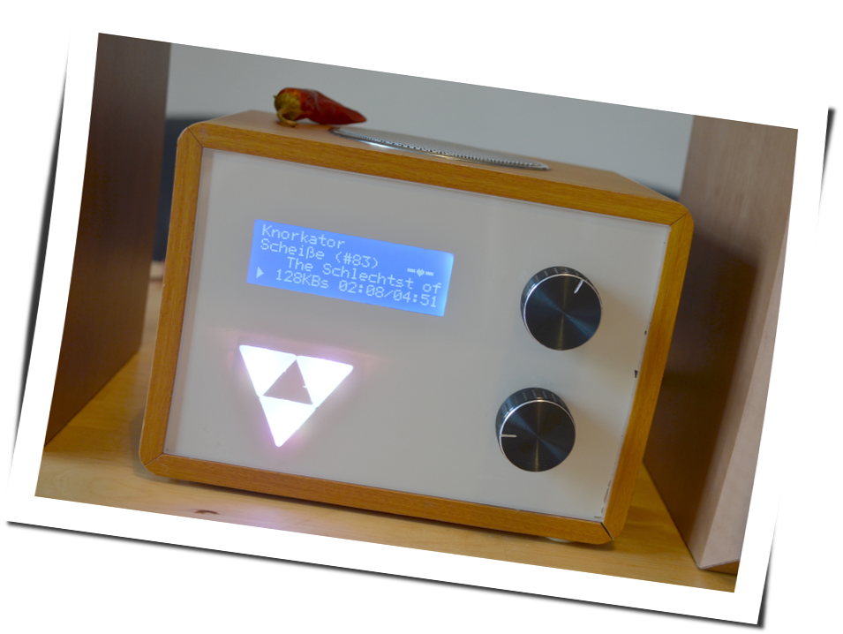
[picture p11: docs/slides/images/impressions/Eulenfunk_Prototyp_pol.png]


-----

:blocky:`Finaler Prototyp #2`

.. note::

    * Hoffentlich koennt ihr das lied nicht erkennen :)

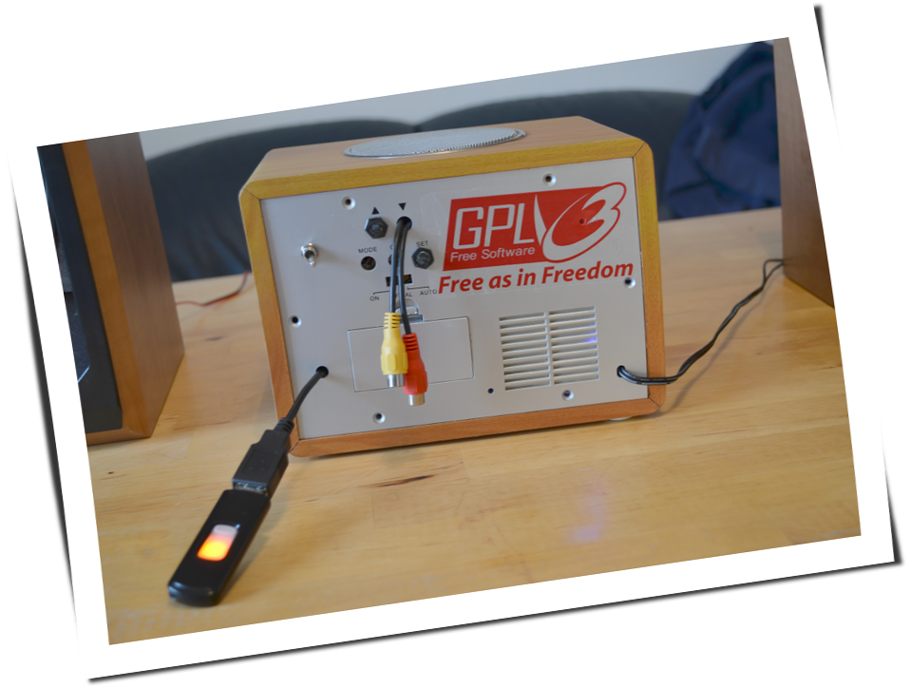
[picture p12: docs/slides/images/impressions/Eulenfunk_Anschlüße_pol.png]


-----

:blocky:`Die Hardware`

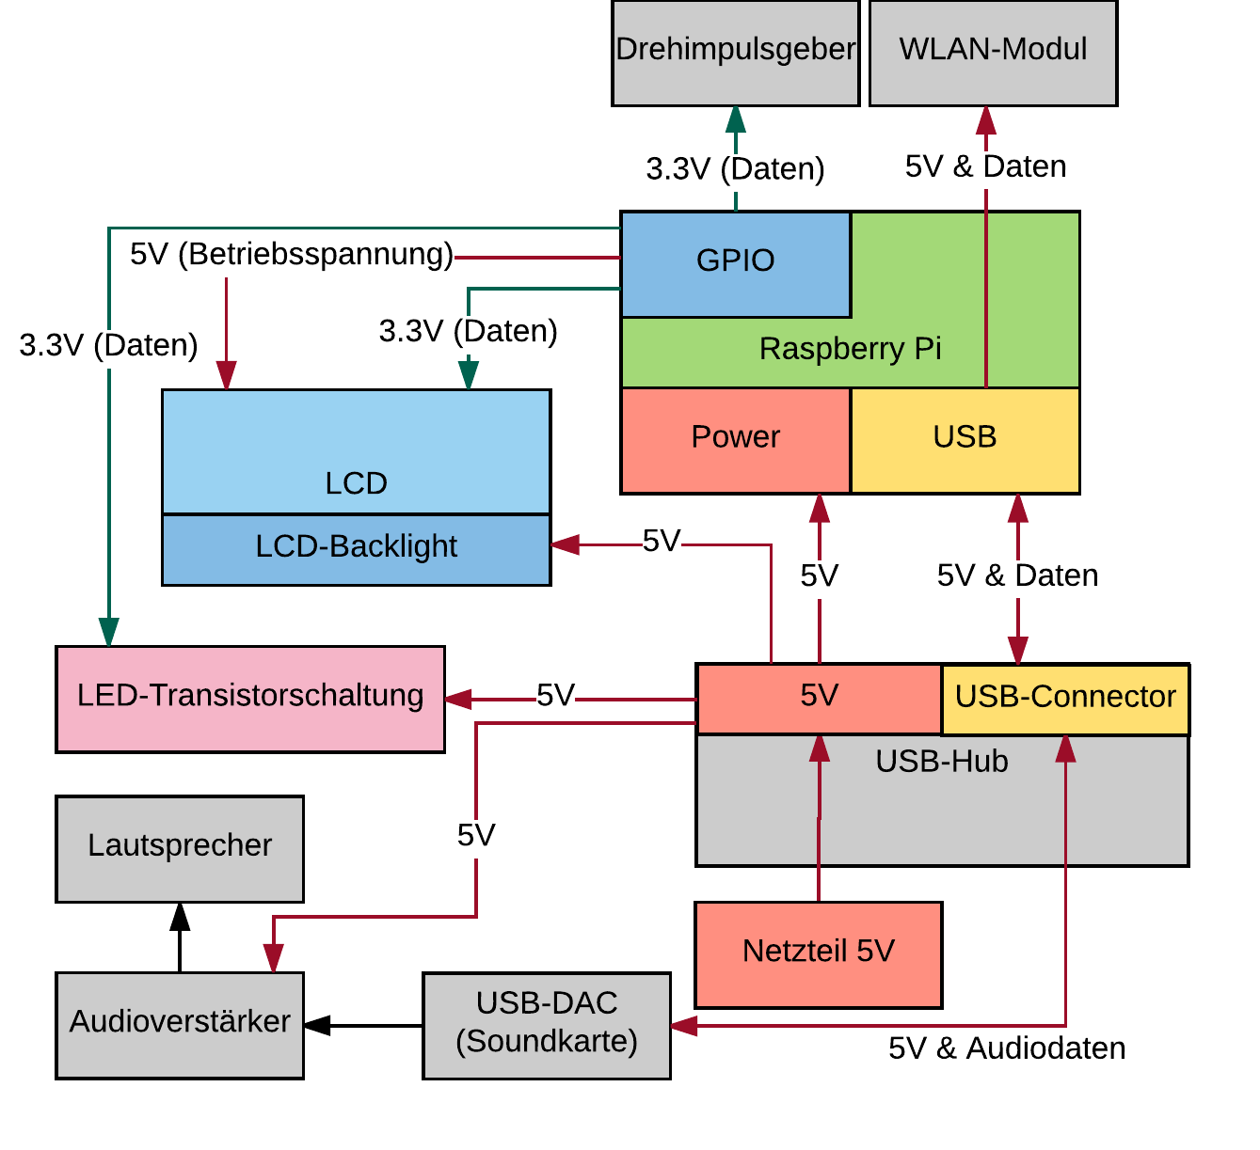
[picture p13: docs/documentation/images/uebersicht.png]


-----

:blocky:`Moodbar`

.. note:: 

    * Bilderraetsel (Jeopardy)
    * Moodbar utility: 1000 samples pro file.
    * Vorberechnet, da ärmliche Performance.
    * Frequenzen.

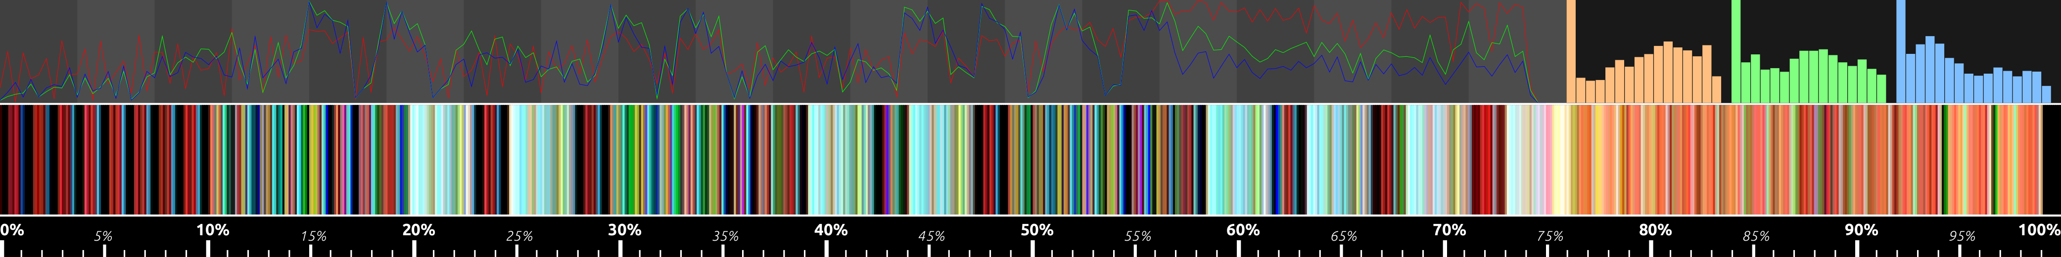
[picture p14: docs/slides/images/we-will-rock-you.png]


|
|
|

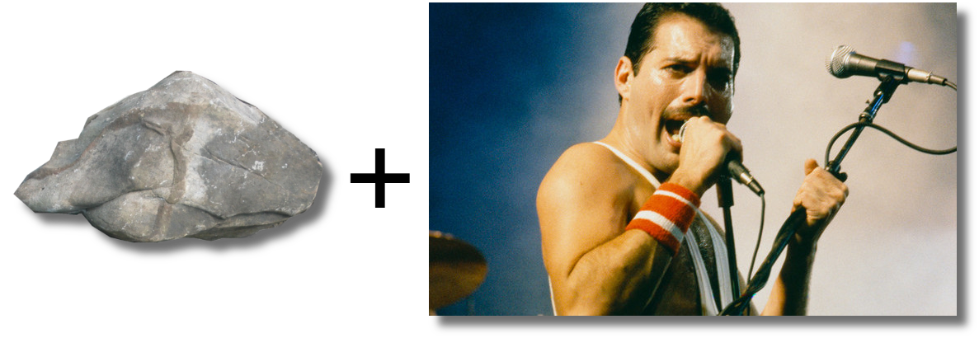
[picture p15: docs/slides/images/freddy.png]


-----

:blocky:`Die Software`

.. note::

    * Ich bin Schuld an der Software.
    * Hat dann doch mehr als 2 Wochen gedauert 
    * Sehr modular
    * Playlisten von USB--Sticks



-----

.. note::

    * Europaeische Variante des LCD.
    * Keine Encoding Tabelle gefunden, daher Abbildung
    * Mapping von unicode 
    * in muehevoller Handarbeit erstellt

:blocky:`Enkodierung`



-----

:blocky:`Bedienung`

.. note:: 

    0. Minimales Bedienkonzept ähnlich Autoradio.



-----

:blocky:`Demonstration`

.. note:: 

    1. Vorher einschalten und auf `If you have Ghosts gehen`
    2. Pause und Schuhu spielen.

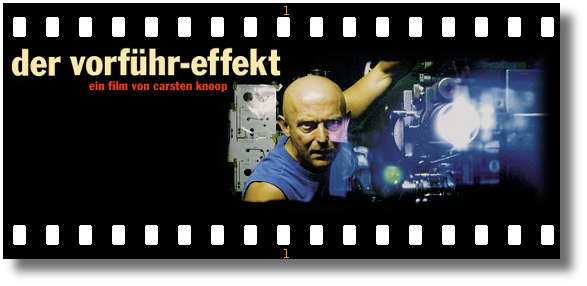
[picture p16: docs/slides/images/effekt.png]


-----

:blocky:`Probleme...`

.. note:: 

    - Probleme mit Netzteilen erlaeutern
    - Backfeed problem erklaeren
    - schwache hardware fuer visuelle Effekte
    - Go war gut, trotz fehlender Libraries.
    - Bedienkonzept gut, trotz Skepsis von Elch.

- Nur wenige Hardware Pins mit PWMs.
- Strom/Spannungsversorgungsprobleme.
- Prinzipiell schwache Hardware.

:blocky:`...und was gut ging:`

- Go ist nett.
- Kein Hausbrand ausgelöst.
- Bedienungskonzept passt.

|



-----

:blocky:`Schuhu (Ende)`

.. note::

    - Sehr eng im Gehäuse, Hitze.
    - Softwareplus: Wettervorhersage, automount stabil, bootzeit.
    - Design verschönern, labels für drehknöpfe, logo
    - in memory alpine

**Prototyp ist noch verbesserungswürdig:**

- Netzteil/USB-Hub.
- Entstörung div. Komponenten.
- Komponenten »besser« im Gehäuse unterbringen.
- Design verschönern? Logo? 
- Softwareoptimierungen.
- Alpine Linux?

**Wir haben:**

- Spaß gehabt.
- Alte Hardware nutzbar gemacht.
- Viel gelernt (Pi-Probleme, Hardware...).
- Ein neues Küchenradio.

.. note::

    none

-------

:id: fin

.. note::

   FRAGEN?

:blocky:`Lust bekommen...`

**Dokumentation & Quellen:**

    https://github.com/studentkittens/eulenfunk

|
|

**(Noch Fragen?)**

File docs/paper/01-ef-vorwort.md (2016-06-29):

---
documentclass: scrreprt
classoption: toc=listof,index=totoc
include-headers:
    - \usepackage{url} 
    - \usepackage[ngerman]{babel}
    - \usepackage{csquotes}
    - \usepackage[babel, german=quotes]{csquotes}
fontsize: 11pt
sections: yes
date: \today
---

\newpage
\setcounter{tocdepth}{1}
\tableofcontents
\listoffigures

\pagenumbering{arabic} 
\setcounter{page}{1}

# Vorwort 

## Hinweis zu den Vorkenntnissen

Das vorliegende Projekt ist im Rahmen einer Studienarbeit im Fach
Hardwaresysteme an der Hochschule Augsburg entstanden. Da die Autoren nicht aus
dem Bereich der *Technischen Informatik* sind, wurden jegliche
hardwareseitigen Arbeiten nach bestem Grundlagenwissen umgesetzt.

## Namensgebung

Der Name des Projektes ist \frqq\texttt{Eulenfunk}\flqq. Passend erschien uns
dieser Name, weil er mit dem Spitznamen einer der Autoren zu tun hat. Auch sind
unserer Meinung nach Eulen sehr faszinierende Tiere, die durch eine gewisse
optische Ästhetik und interessante, manchmal verwirrende, Verhaltensstrukturen
auffallen. Der Suffix »-funk« verleiht dem Name zudem durchaus etwas
majestätisches.

## Zielsetzung 

Das grundlegende Projektziel ist aus vorhandenen alten Hardware--Komponenten ein
möglichst optisch und klanglich ansprechendes Internetradio zu entwickeln. Dabei
liegt der Schwerpunkt vor allem auch auf einem guten Kosten/Nutzen--Verhältnis.
Als Basis für das Projekt dient ein defektes Analog--Radio und ein *Raspberry
Pi* aus dem Jahr 2012.

Diese Studienarbeit soll einen Überblick über die verwendeten, beziehungsweise
benötigten Komponenten für den Bau eines *Raspberry Pi*--Internetradios
verschaffen. Anschließend soll das Wissen für die Ansteuerung bestimmter
Hardware--Komponenten mittels der *Raspberry Pi*--GPIO[^GPIO] Schnittstelle vermittelt
werden.

\begin{figure}[h!]
  \centering
\includegraphics[width=0.7\textwidth]{images/eulenfunk.png}
  \caption{Foto vom aktuellen Prototypen.}
  \label{fertig}
\end{figure}

\newpage
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

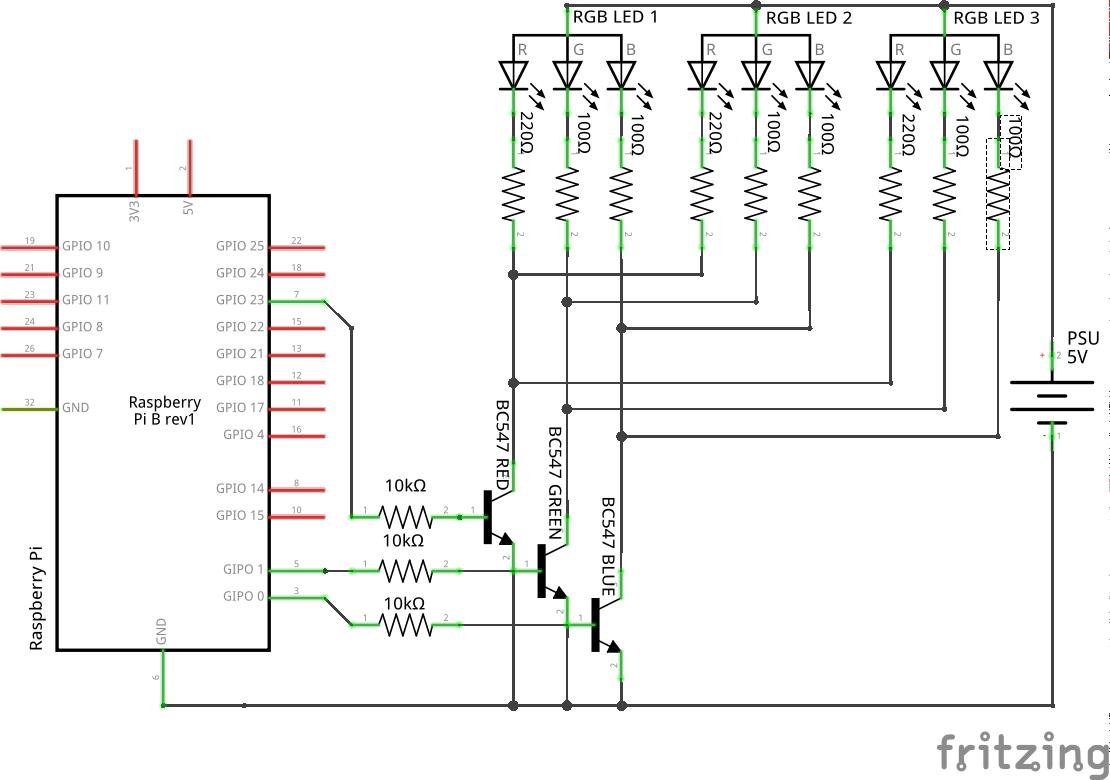
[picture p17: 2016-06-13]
docs/paper/images/transistorled.png

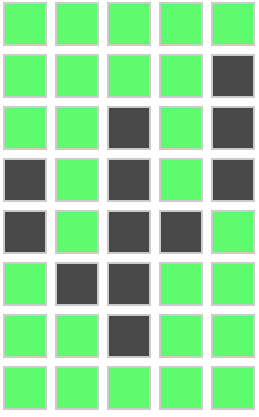
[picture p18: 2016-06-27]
docs/paper/images/symbols/cactus.png

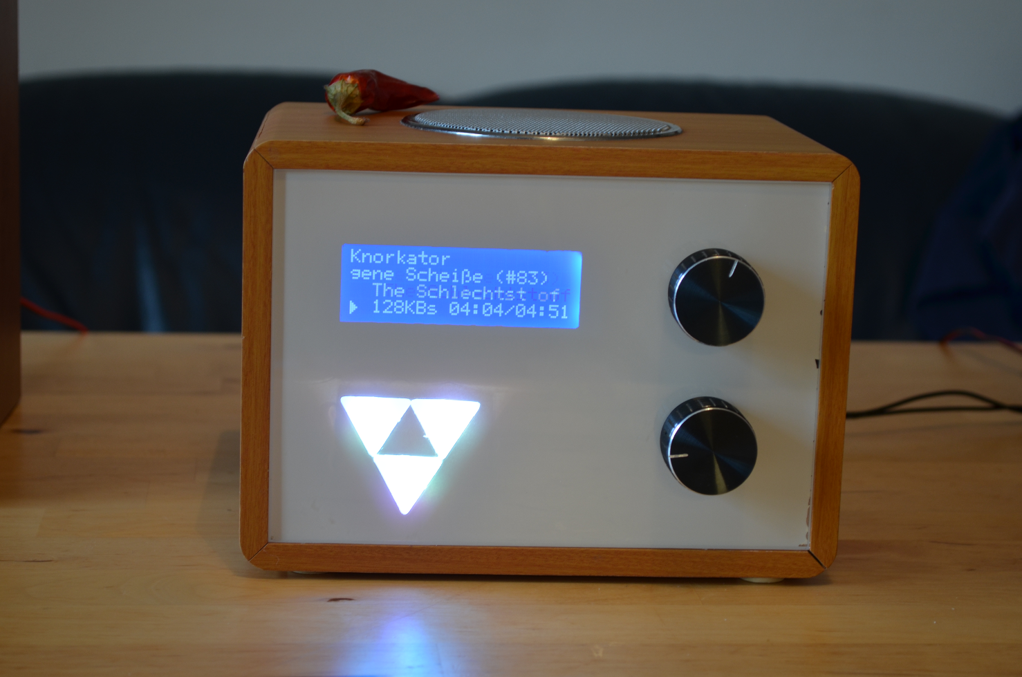
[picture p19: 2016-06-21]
docs/paper/images/front_2.png

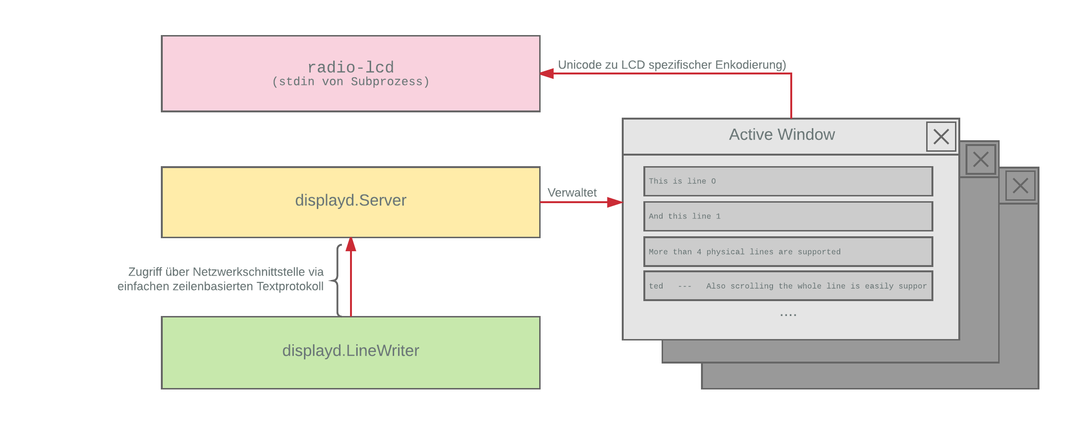
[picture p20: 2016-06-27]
docs/paper/images/eulenfunk-displayd.png

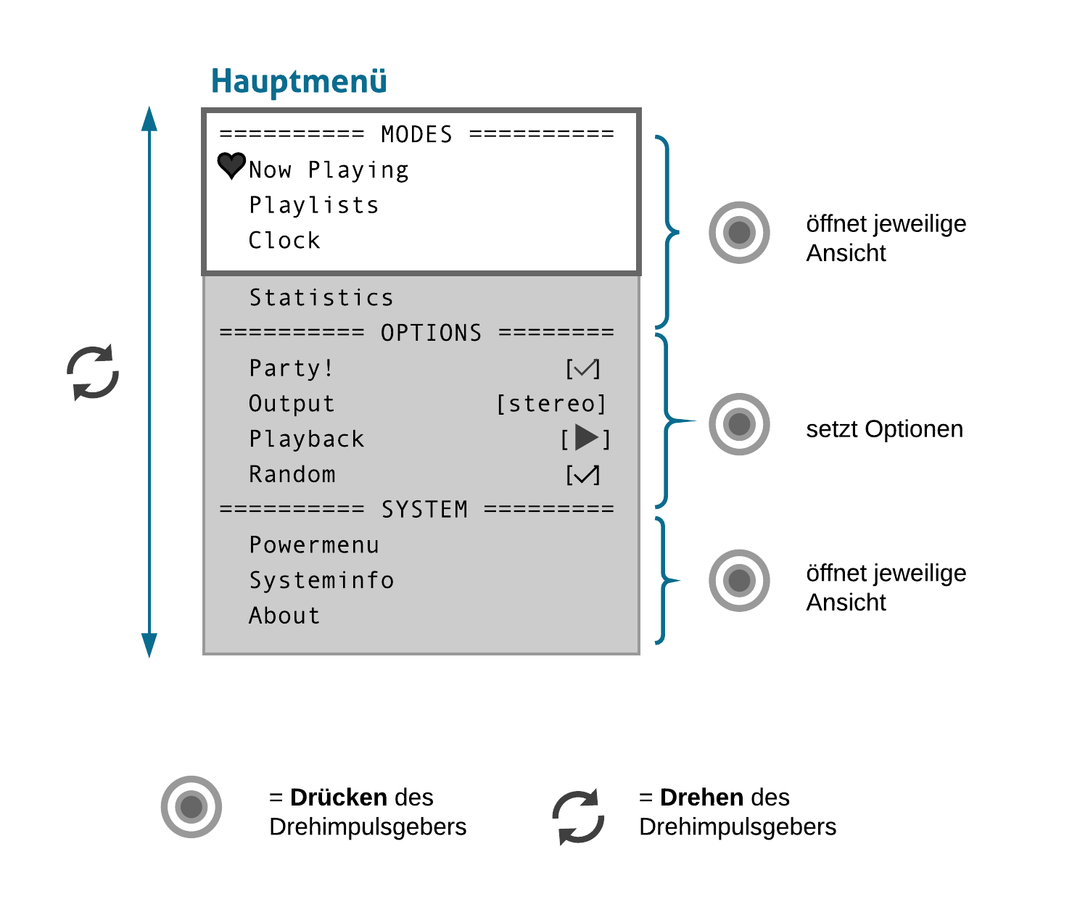
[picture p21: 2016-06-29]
docs/paper/images/hauptmenue.png

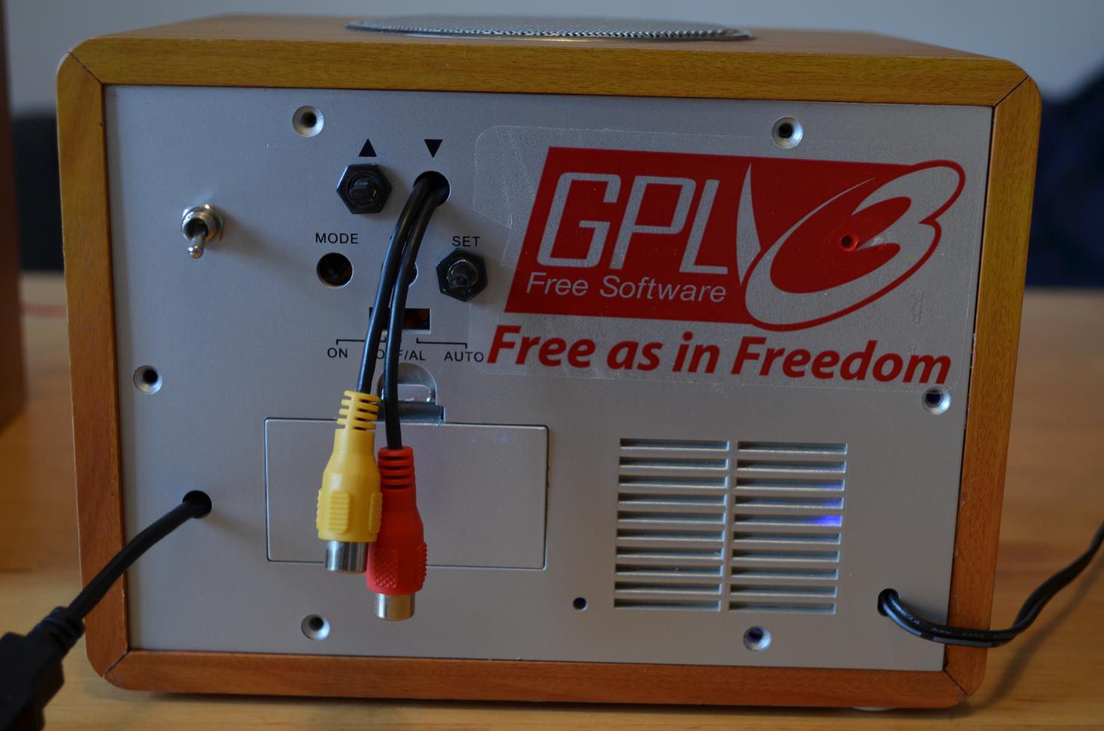
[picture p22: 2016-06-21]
docs/paper/images/back_2.png

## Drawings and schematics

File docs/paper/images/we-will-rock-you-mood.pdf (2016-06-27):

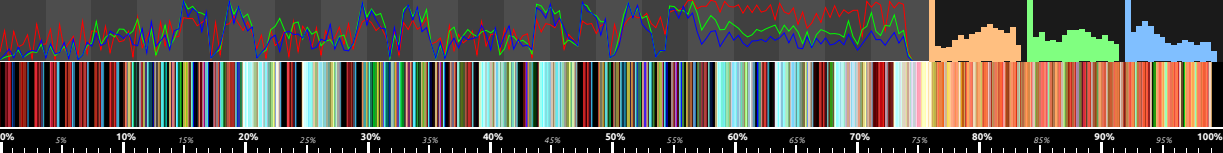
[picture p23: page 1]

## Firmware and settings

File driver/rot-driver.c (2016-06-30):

#include <wiringPi.h> 
#include <stdio.h>
#include <stdlib.h>
#include <stdint.h>
#include <stdbool.h>
#include <stdio.h>
#include <time.h>
#include <string.h>
#include <math.h>

#include <fcntl.h>
#include <unistd.h>
#include <sys/time.h>
#include <sys/types.h>
#include <sys/stat.h>

#define MAX_ENCODERS 8

#define ROTARY_PIN_A  12
#define ROTARY_PIN_B  13
#define ROTARY_BUTTON 14

#define ROTATY_INCREMENT (0.25)

struct encoder {
    int pin_a;
    int pin_b;
    int pin_btn;

    volatile double value;
    volatile int lastEncoded;

    volatile struct timeval button_time;
    volatile bool button_was_pressed;
    volatile bool button_was_released;
    volatile bool button_curr_pressed;
};

struct encoder encoders[MAX_ENCODERS];

int N_ENCODERS = 0;

void updateButton() {
    struct encoder *encoder = encoders;
    for(; encoder < encoders + N_ENCODERS; encoder++) {
        int button_press = digitalRead(encoder->pin_btn);
        if(button_press == LOW) {
            /* Button was pressed */
            gettimeofday((struct timeval *)&encoder->button_time, NULL);
            encoder->button_was_pressed = true;
            encoder->button_curr_pressed = true;
        } else {
            /* Button was released */
            encoder->button_time.tv_sec = 0;
            encoder->button_time.tv_usec = 0;
            encoder->button_was_released = true;
            encoder->button_curr_pressed = false;
        }
    }
} 

void updateEncoders() {
    struct encoder *encoder = encoders;
    for(; encoder < encoders + N_ENCODERS; encoder++) {
        int MSB = digitalRead(encoder->pin_a);
        int LSB = digitalRead(encoder->pin_b);

        int encoded = (MSB << 1) | LSB;
        int sum = (encoder->lastEncoded << 2) | encoded;

        if(sum == 0b1101 || sum == 0b0100 || sum == 0b0010 || sum == 0b1011) encoder->value -= ROTATY_INCREMENT;
        if(sum == 0b1110 || sum == 0b0111 || sum == 0b0001 || sum == 0b1000) encoder->value += ROTATY_INCREMENT;

        encoder->lastEncoded = encoded;
    }
}

struct encoder *setupencoder(int pin_a, int pin_b, int pin_btn) {
    if (N_ENCODERS > MAX_ENCODERS) {
        printf("Maximum number of encodered exceded: %i\n", MAX_ENCODERS);
        return NULL;
    }

    struct encoder *newencoder = encoders + N_ENCODERS++;
    newencoder->pin_a = pin_a;
    newencoder->pin_b = pin_b;
    newencoder->pin_btn = pin_btn;
    newencoder->value = 0;
    newencoder->lastEncoded = 0;
    newencoder->button_was_pressed = false;
    newencoder->button_was_released = false;

    pinMode(pin_a, INPUT);
    pinMode(pin_b, INPUT);
    pinMode(pin_btn, INPUT);

    pullUpDnControl(pin_a, PUD_UP);
    pullUpDnControl(pin_b, PUD_UP);
    pullUpDnControl(pin_btn, PUD_UP);

    wiringPiISR(pin_a,INT_EDGE_BOTH, updateEncoders);
    wiringPiISR(pin_b,INT_EDGE_BOTH, updateEncoders);
    wiringPiISR(pin_btn,INT_EDGE_BOTH, updateButton);

    return newencoder;
}

int main(void) {
    piHiPri(20);
    wiringPiSetup();

    struct encoder *encoder = setupencoder(
            ROTARY_PIN_A,
            ROTARY_PIN_B,
            ROTARY_BUTTON
            );

    long last_value = -1;
    double hold_time = 0;

    while (1) {
        // Divide by three since it counts 
        // about 3 value increments per "tick" which is too much.
        long curr = lround(encoder->value);
        if(curr != last_value) {
            printf("v %ld\n", curr);
            fflush(stdout);
            last_value = curr;
        }

        if(encoder->button_was_pressed && encoder->button_curr_pressed) {
            encoder->button_was_pressed = false;
            printf("p 1\n");
            fflush(stdout);
        }

        if(encoder->button_time.tv_sec > 0) {
            struct timeval now;
            gettimeofday(&now, NULL);

            hold_time = now.tv_sec - encoder->button_time.tv_sec;
            hold_time += (now.tv_usec - encoder->button_time.tv_usec) / (1000.0 * 1000.0);
            printf("t %f\n", hold_time);
            fflush(stdout);
        } else {
            hold_time = 0;
        }

        if(encoder->button_was_released && !encoder->button_curr_pressed) {
            encoder->button_was_released = false;
            printf("p 0\n");
            fflush(stdout);
        }

        // Sleep for a short amount to save cpu-time:
        struct timespec delay = {
            .tv_sec = 0,
            .tv_nsec = 1000 * 1000 * 25,
        };

        nanosleep(&delay, NULL);
    }

    return EXIT_SUCCESS;
}

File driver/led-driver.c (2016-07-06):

#include <stdio.h>
#include <stdint.h>
#include <stdbool.h>
#include <stdlib.h>
#include <string.h>
#include <wiringPi.h>
#include "softPwm.h"

#define PIN_RED   7
#define PIN_GREEN 9
#define PIN_BLUE  8

#define CLAMP(x, low, high)  (((x) > (high)) ? (high) : (((x) < (low)) ? (low) : (x)))

static void usage(char *name) {
    fprintf(stderr, "usage:\n");
    fprintf(stderr, "  %s on  ....... turn on LED (white)\n", name);
    fprintf(stderr, "  %s off ....... turn off LED\n", name);
    fprintf(stderr, "  %s cat ....... read rgb tuples from stdin\n", name);
    fprintf(stderr, "  %s rgb  r g b  Set LED color to r,g,b\n", name);
    fprintf(stderr, "  %s hex #FFFFFF Set LED color from hexstring\n", name);
    fprintf(stderr, "  %s fade ...... Show a fade for debugging\n", name);
    exit(1);
}

static int linearize(int v) {
    // Half linear and half quadratic mix:
    return ((v / 256.) * (v / 256.)) * 128 + (v / 128.);
}

static void set_rgb(int r, int g, int b) { 
    softPwmWrite(PIN_RED, linearize(r));
    softPwmWrite(PIN_GREEN, linearize(g));
    softPwmWrite(PIN_BLUE, linearize(b));
}

static int string_to_col(const char * arg) {
    return CLAMP(strtol(arg,NULL,10),0,255);
}

static void set_rgb_from_arr(const char ** arr) {
    int r = string_to_col(arr[0]);
    int g = string_to_col(arr[1]);
    int b = string_to_col(arr[2]);

    set_rgb(r, g, b);
}

static void hexstring_to_rgb(const char * str, unsigned * r, unsigned * g, unsigned * b) {
    char * is_err = NULL;
    if(!(str && r && g && b))
        return;

    union {
        uint32_t val;
        unsigned char arr[sizeof(uint32_t)];
    } rgb_int = {.val=0};

    rgb_int.val = strtoul(str,&is_err, 10);

    if(is_err == NULL || *is_err == '\n' || *is_err == 0) {
        // Little endian:
        *r = rgb_int.arr[2];
        *g = rgb_int.arr[1];
        *b = rgb_int.arr[0];
    }
}

int main(int argc, char **argv) {
    piHiPri(30);
    wiringPiSetup();

    if(argc < 2) {
	    usage(argv[0]);
    }

    softPwmCreate(PIN_RED, 0, 255);
    softPwmCreate(PIN_GREEN, 0, 255);
    softPwmCreate(PIN_BLUE, 0, 255);

    if(strcasecmp(argv[1], "cat") == 0) {
        const int size = 512;
        char buf[size + 1];
        const char * rgb[3] = {0,0,0};
        int i = 0;

        for(;;) {
            memset(buf, 0, size);
            if(fgets(buf,size,stdin) == NULL) {
                puts("Got EOF, quitting");
                break;
            }

            if(buf[0] == '#') {
                unsigned r = 0, g = 0, b = 0;
                hexstring_to_rgb(&buf[1], &r, &g, &b);
                set_rgb(r, g, b);
            } else {
                bool is_valid = true;
                char * node = buf;

                for(i = 0; i < 3; i++) {
                    rgb[i] = node;
                    node = strpbrk(node," \n");
                    if(node != NULL) {
                        *node++ = 0;
                    } else {
                        is_valid = false;
                        break;
                    }
                }

                if(is_valid) {
                    set_rgb_from_arr(rgb);
                }
            }
        }
    } else if(strcasecmp(argv[1], "fade") == 0) {
	for(int i = 0; i < 256; i++) {
		set_rgb(i, 0, 0);
		delay(10);
	}
	for(int i = 0; i < 256; i++) {
		set_rgb(0, i, 0);
		delay(10);
	}
	for(int i = 0; i < 256; i++) {
		set_rgb(0, 0, i);
		delay(10);
	}
	for(int i = 0; i < 256; i++) {
		set_rgb(i, i, i);
		delay(10);
	}
    } else if(strcasecmp(argv[1], "rgb") == 0 && argc > 4) {
        set_rgb_from_arr((const char**)&argv[2]);
    } else if(strcasecmp(argv[1], "hex") == 0) {
        unsigned r = 0, g = 0, b = 0;
        printf("%s\n",&argv[2][1]);
        hexstring_to_rgb(&argv[2][1], &r, &g, &b);
        set_rgb(r, g, b);
    } else if(strcasecmp(argv[1], "off")) {
        set_rgb(0, 0, 0);
    } else if(strcasecmp(argv[1], "on")) {
        set_rgb(0, 0, 0);
    } else {
        usage(argv[0]);
    }

    return EXIT_SUCCESS;
}

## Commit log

2016-06-09 Added LED Driver based on catlight and wiringPis software PWM
2016-06-10 Add dummy driver derived from github.com/rehn/gpio/blob/master/lcd.go
2016-06-10 try out driver.py then...
2016-06-10 Use existing python script and make it act as lcd-driver
2016-06-10 Add driver.c for the lcd (yet another attempt to dump python)
2016-06-10 Implement actual c driver functionality
2016-06-11 Add rotary "driver"
2016-06-11 Use original driver and pipe to fifo...
2016-06-11 Slight cleanup and add (working!) driver for the rotary
2016-06-11 use piHiPri in the hope it makes the driver run more stable (probably not)
2016-06-12 Raspberry Pi hardware ref bib added.
2016-06-12 Some fixes on the pi itself
    [led-driver.c]
2016-06-12 GPIO and RGB-LED wiring added.
2016-06-12 Add --driver for lightd
2016-06-13 Ignore bad linenos in lcd-driver.c
2016-06-13 Hardwaredesign images updated
    [lcd.fzz]
2016-06-13 Hardwaredesign images updated #2
    [transistor_led.fzz]
2016-06-13 Make driver redraw only chars what are definitely needed
2016-06-13 Squash a few bugs on the RaPi
    [rot-driver.c]
2016-06-14 Docs update.
    [rotary.fzz, transistor_ledn.fzz]
2016-06-15 Fix the whacky fading on the LEDs
    [led-driver.c, softPwm.c]
2016-06-16 Reset actionDone when releasing the button
2016-06-16 lcd-driver: Support some more custom chars
2016-06-17 Doc update.
    [led.fzz, transistor_ledn2.fzz]
2016-06-17 systemd seems to work... at least currently.
2016-06-18 Make sure focus gets switched to mpd initially after short timeout
2016-06-18 Attemtp to cleanup the toggle button mess
2016-06-18 Doc and Design update.
    [lcd.fzz]
2016-06-18 Formatf -> Printf
2016-06-18 Make eulenfunk fully interruptable again
2016-06-19 display: fix the space of death (led to no output at all)
2016-06-20 Remove the ৹C that did not render right
2016-06-20 ui: Resume playback when switching outputs
2016-06-20 ui: add a flash effect when powering off
2016-06-20 rotary: try to de-bounce the button
2016-06-21 automount: add new shiny daemon that can mount usb sticks and create playlists from it
2016-06-21 Bit nicer menu and actually show uptime (not current time, oops)
2016-06-21 couple of usability fixes
2016-06-21 display: Make LineWriter support convinience functions for the protocol beside the low-level Printf
2016-06-22 automount: first remove playlist, then remove mount
2016-06-22 Spellcheck and other corrections
    [lcd.fzz, rotary.fzz]
2016-06-28 Rename docs/documentation to more sane docs/paper
    [lcd.fzz, led.fzz, rotary.fzz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]
2016-06-28 current list
2016-06-28 Fritzing files moved.
    [lcd.fzz, rotary.fzz, transistor_led.fzz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]
2016-06-28 Fritzing files moved #2.
    [led.fzz]
2016-06-28 Makefile latexmk cleanup added.
    [led.fzz, transistor_led.fzz, transistor_ledn.fzz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]
2016-06-28 Software docs alpha - need to fix all those TODOs
    [rot-driver.c]
2016-06-28 ARM needs LinearRGB...
2016-06-30 driver: rot-driver: further lower the polling delay
2016-07-02 ui: weather: periodically switch to day #1, #2 and #3
2016-07-03 pi: switch to main music server
2016-07-06 driver/led: Linearize the brightness using a mix of linear and quadratic fading
